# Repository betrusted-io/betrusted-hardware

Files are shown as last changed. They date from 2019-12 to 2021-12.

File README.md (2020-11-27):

# betrusted-hardware

This is the Betrusted hardware design files repository.

All the designs are preliminary and have bugs. You have been warned. 

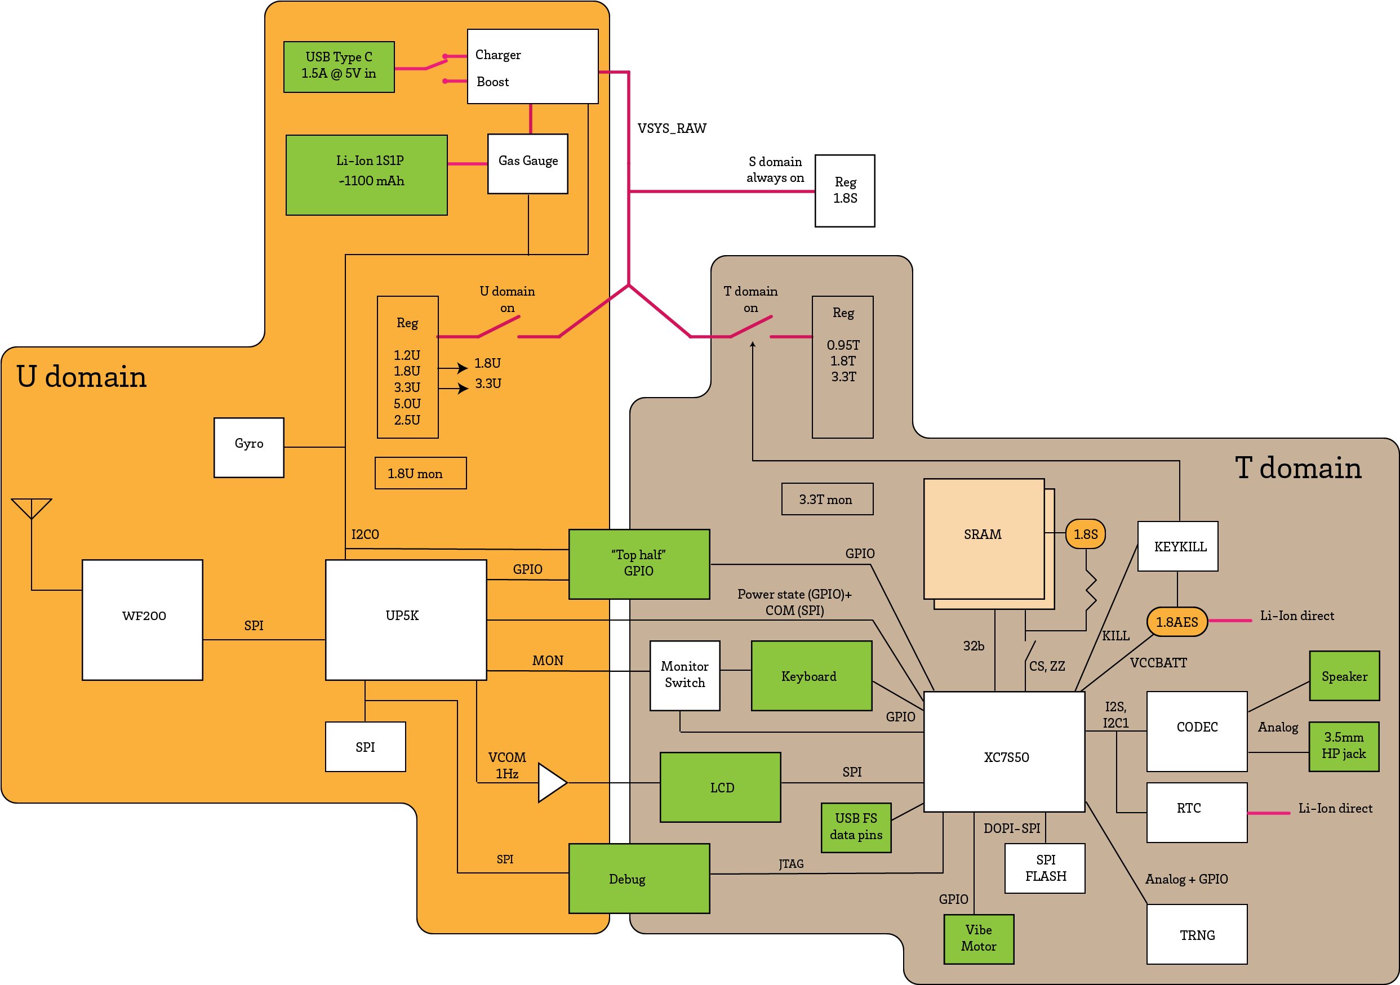
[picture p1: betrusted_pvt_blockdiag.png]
block diagram


Above is a block diagram of the mainboard, as of PVT1.

## Contribution Guidelines



Please see [CONTRIBUTING](CONTRIBUTING.md) for details on
how to make a contribution.

Please note that this project is released with a
[Contributor Code of Conduct](CODE_OF_CONDUCT.md).
By participating in this project you agree to abide its terms.

## License

Copyright © 2019

Licensed under the [CERN OHL v1.2](https://ohwr.org/project/licenses/wikis/cern-ohl-v1.2) [LICENSE](LICENSE)

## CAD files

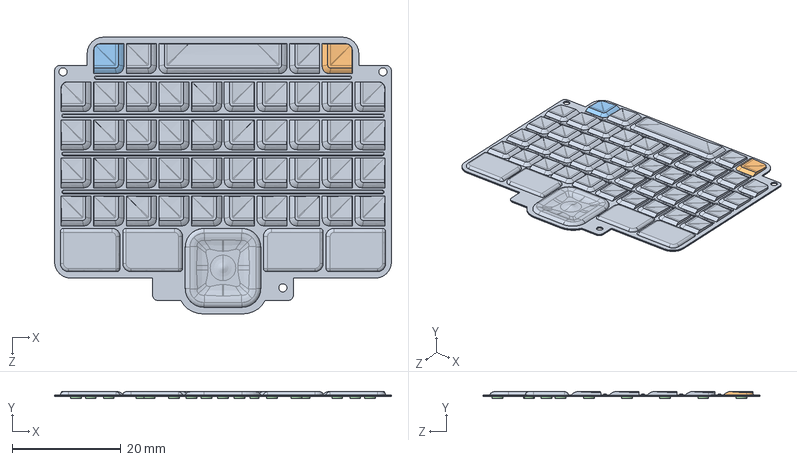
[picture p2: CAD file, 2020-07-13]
kbd-v3/overlays/kbd-v5-dvt.SLDASM
61.9 x 1.23 x 50.9 mm
kbd-v5-dvt
keycap
Mirrorkeycap
kbd-v5-bumps

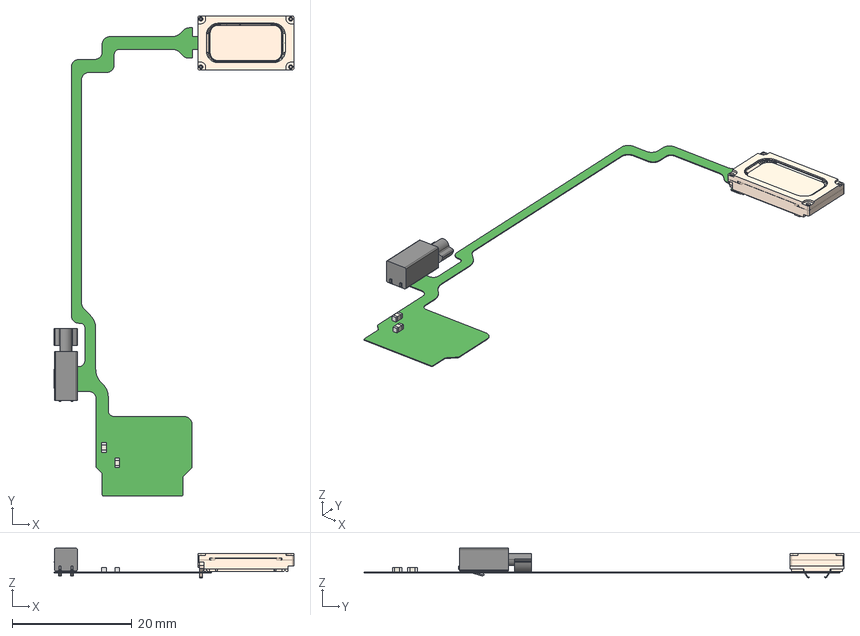
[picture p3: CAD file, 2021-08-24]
fpc-pvt2/bt-fpc-pvt2b.step
40.0 x 80.1 x 4.94 mm
vibe_motor_jinlong_Z32th7b2882001d_RGB4408131
CUI_CMS-16093-076S-67
Extruded x 6

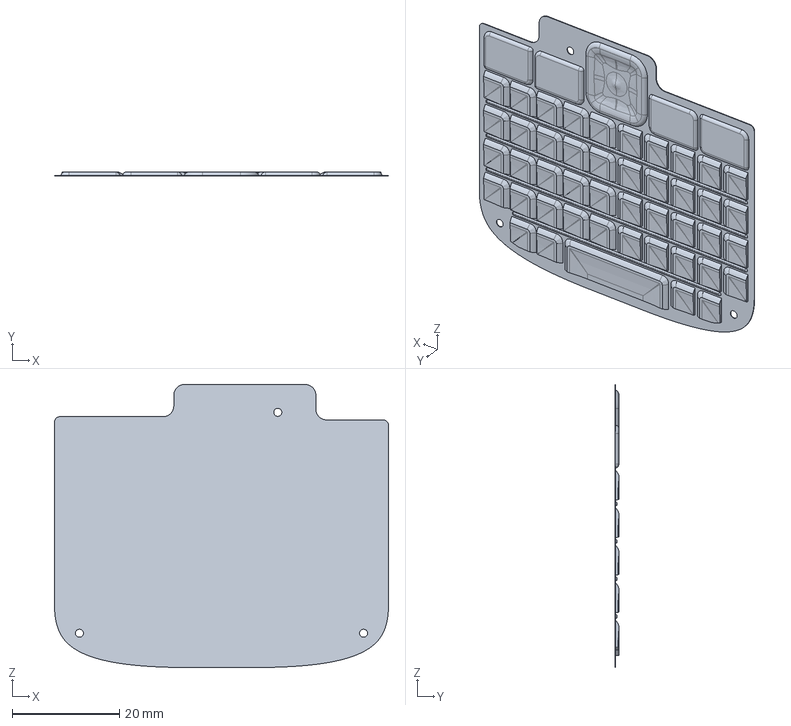
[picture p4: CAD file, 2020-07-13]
kbd-v3/overlays/kbd-v4-vendor.stp
62.3 x 0.725 x 52.8 mm

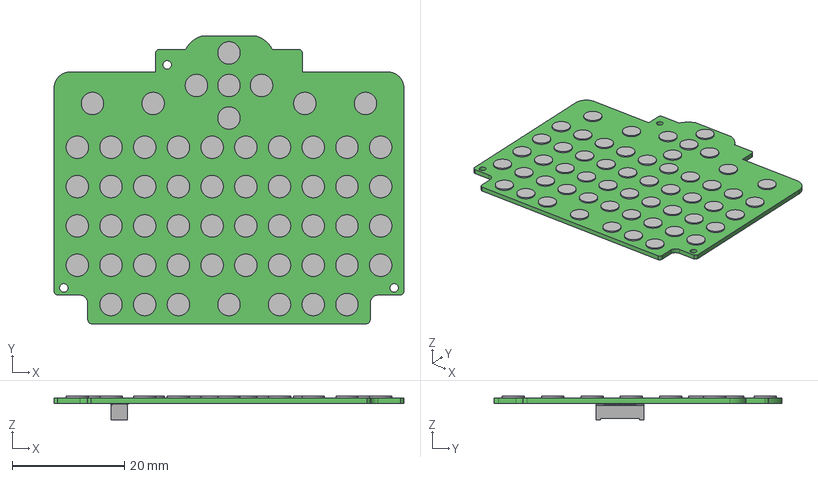
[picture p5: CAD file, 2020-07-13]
kbd-v3/pcb/bt-kbd-v3a.step
62.3 x 51.2 x 4.19 mm
DF40HC(3.0)-30DS

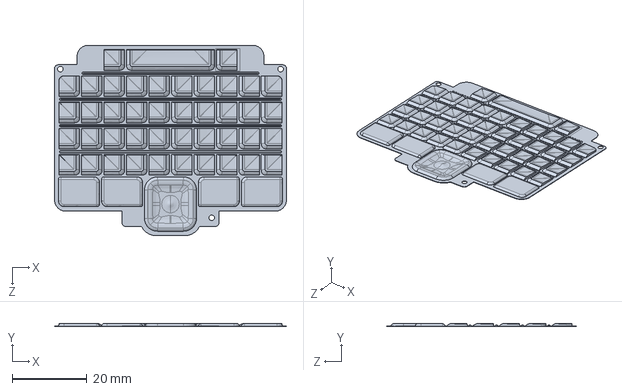
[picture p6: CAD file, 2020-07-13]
kbd-v3/overlays/kbd-v5-keycap.SLDPRT
61.9 x 0.725 x 50.9 mm

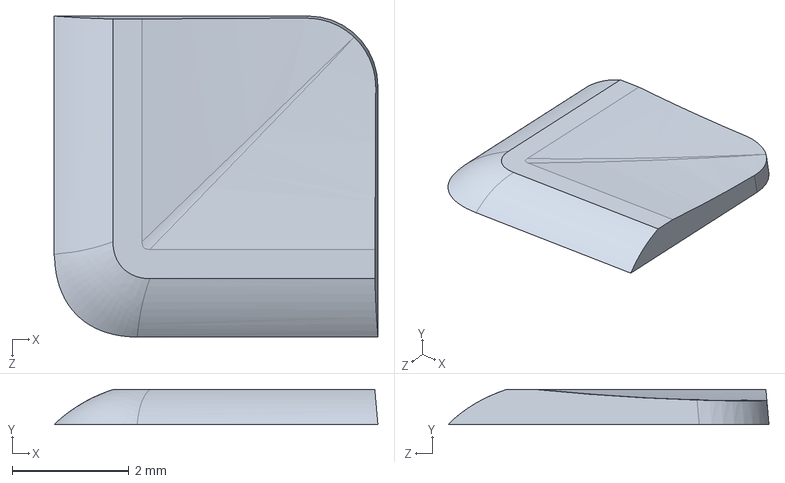
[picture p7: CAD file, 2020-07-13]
kbd-v3/overlays/keycap.sldprt
5.55 x 0.6 x 5.50 mm

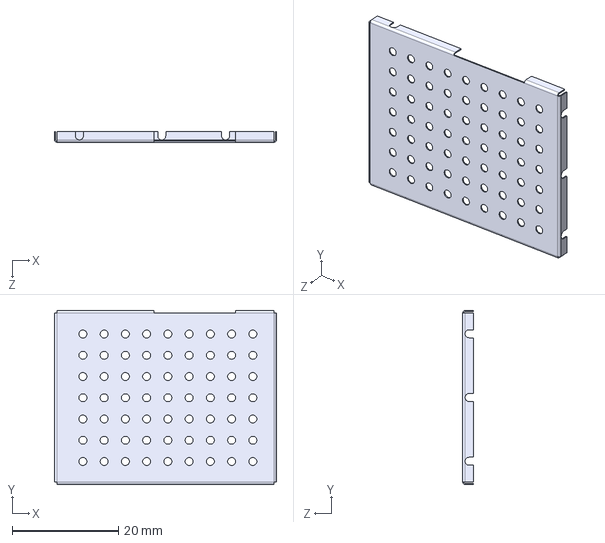
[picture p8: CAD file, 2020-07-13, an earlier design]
case-v1/t-domain-shield-032520.STEP
41.8 x 32.8 x 2.00 mm

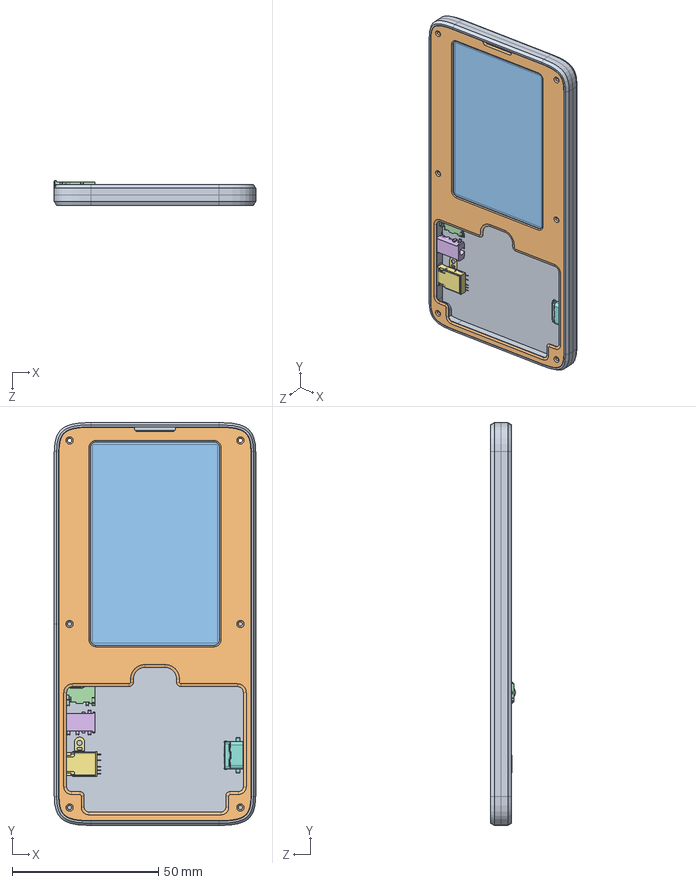
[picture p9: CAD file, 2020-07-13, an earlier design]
case-v1/betrusted-dvt1-top-sketch.SLDASM
69.0 x 138.0 x 8.50 mm
bottom-case
front-bezel
sharp_ls032b7dd02-folded-cable
CUI_SJ-43504-SMT-TR x 2
CX90B1-24P.stp
CUI_DEVICES_SJ-43615TS-SMT-TR
CUI_DEVICES_SJ-3542AS-SMT-TR-67
c-1-2295018-2-b-3d
pcb-max-extent

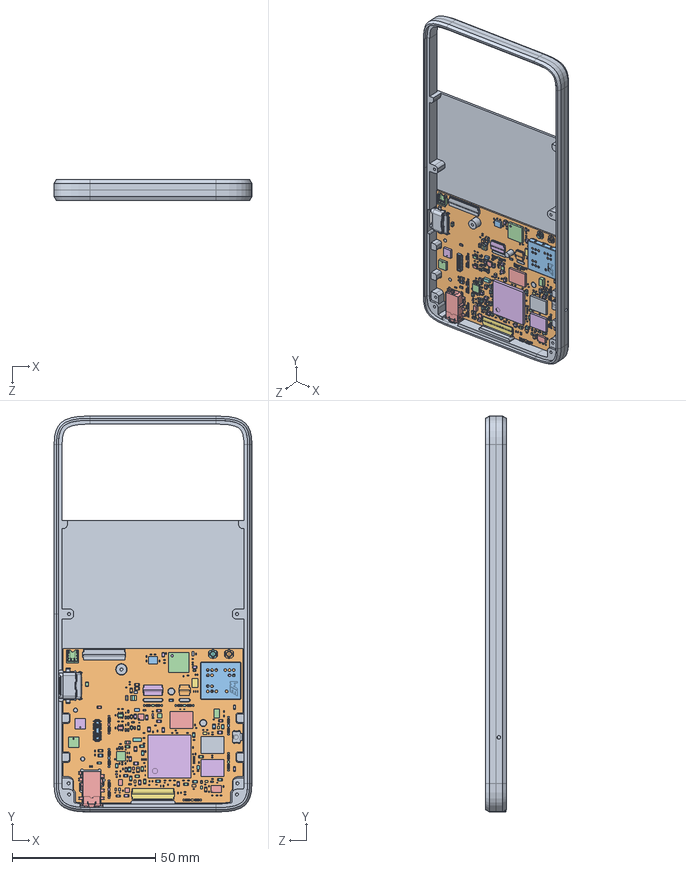
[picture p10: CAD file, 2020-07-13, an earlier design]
case-v1/dvt1-pcb-fitting.SLDASM
69.0 x 138.0 x 7.20 mm
bottom-case
36900000_Download_STP_WE-SHC-36900000_rev1^T-SHIELD8testfit_dvt1-test-mb(2)_dvt1-test-mb
36900000_Download_STP_WE-SHC-36900000_rev1^T-SHIELD7testfit_dvt1-test-mb(2)_dvt1-test-mb
36900000_Download_STP_WE-SHC-36900000_rev1^T-SHIELD6testfit_dvt1-test-mb(2)_dvt1-test-mb
36900000_Download_STP_WE-SHC-36900000_rev1^T-SHIELD5testfit_dvt1-test-mb(2)_dvt1-test-mb
Extruded^6956128896_U13Mtestfit_dvt1-test-mb(2)_dvt1-test-mb
Extruded-0^7163059696_R14Mtestfit_dvt1-test-mb(2)_dvt1-test-mb x 2
Extruded-1^7163062416_R14Mtestfit_dvt1-test-mb(2)_dvt1-test-mb
Extruded-2^7161943424_L10Mtestfit_dvt1-test-mb(2)_dvt1-test-mb x 2
Extruded-3^7161944304_L10Mtestfit_dvt1-test-mb(2)_dvt1-test-mb
Extruded-4^6098454064_J10Mtestfit_dvt1-test-mb(2)_dvt1-test-mb x 2
Extruded-5^6098454464_J10Mtestfit_dvt1-test-mb(2)_dvt1-test-mb
Extruded-6^6098170912_C20Mtestfit_dvt1-test-mb(2)_dvt1-test-mb
Extruded-7^6098171472_C20Mtestfit_dvt1-test-mb(2)_dvt1-test-mb x 2
Extruded-8^6480486112_C19Mtestfit_dvt1-test-mb(2)_dvt1-test-mb
Extruded-9^6480485872_C19Mtestfit_dvt1-test-mb(2)_dvt1-test-mb x 2
FH34SRJ-4S-0.5SH^P13Wtestfit_dvt1-test-mb(2)_dvt1-test-mb
Open_CASCADE_STEP_translator_6.8_3.1.1^Terminal_7706544704_D15Wtestfit_dvt1-test-mb(2)_dvt1-test-mb
Open_CASCADE_STEP_translator_6.8_3.1.2^Terminal_7706544704_D15Wtestfit_dvt1-test-mb(2)_dvt1-test-mb
Open_CASCADE_STEP_translator_6.8_3.2.1^Mid_Body_7706544704_D15Wtestfit_dvt1-test-mb(2)_dvt1-test-mb
Open_CASCADE_STEP_translator_6.8_3.1.1^Terminal_7706544704_D14Wtestfit_dvt1-test-mb(2)_dvt1-test-mb
Open_CASCADE_STEP_translator_6.8_3.1.2^Terminal_7706544704_D14Wtestfit_dvt1-test-mb(2)_dvt1-test-mb
Open_CASCADE_STEP_translator_6.8_3.2.1^Mid_Body_7706544704_D14Wtestfit_dvt1-test-mb(2)_dvt1-test-mb
Open_CASCADE_STEP_translator_6.8_3.1.1^Terminal_7706544704_D13Wtestfit_dvt1-test-mb(2)_dvt1-test-mb
Open_CASCADE_STEP_translator_6.8_3.1.2^Terminal_7706544704_D13Wtestfit_dvt1-test-mb(2)_dvt1-test-mb
Open_CASCADE_STEP_translator_6.8_3.2.1^Mid_Body_7706544704_D13Wtestfit_dvt1-test-mb(2)_dvt1-test-mb
Open_CASCADE_STEP_translator_6.8_3.1.1-15^Terminal-1_9704169984_D12Wtestfit_dvt1-test-mb(2)_dvt1-test-mb
Open_CASCADE_STEP_translator_6.8_3.1.2-16^Terminal-1_9704169984_D12Wtestfit_dvt1-test-mb(2)_dvt1-test-mb
Open_CASCADE_STEP_translator_6.8_3.2.1-17^Mid_Body-1_9704169984_D12Wtestfit_dvt1-test-mb(2)_dvt1-test-mb
Open_CASCADE_STEP_translator_6.8_3.1.1-15^Terminal-1_9704169984_D11Wtestfit_dvt1-test-mb(2)_dvt1-test-mb
Open_CASCADE_STEP_translator_6.8_3.1.2-16^Terminal-1_9704169984_D11Wtestfit_dvt1-test-mb(2)_dvt1-test-mb
Open_CASCADE_STEP_translator_6.8_3.2.1-17^Mid_Body-1_9704169984_D11Wtestfit_dvt1-test-mb(2)_dvt1-test-mb
36900000_Download_STP_WE-SHC-36900000_rev1^T-SHIELD4testfit_dvt1-test-mb(2)_dvt1-test-mb
36900000_Download_STP_WE-SHC-36900000_rev1^T-SHIELD3testfit_dvt1-test-mb(2)_dvt1-test-mb
36900000_Download_STP_WE-SHC-36900000_rev1^T-SHIELD2testfit_dvt1-test-mb(2)_dvt1-test-mb
CUI_SJ-43504-SMT-TR^P10Utestfit_dvt1-test-mb(2)_dvt1-test-mb
Open_CASCADE_STEP_translator_6.8_13.2.1^Body_6846069104_U11Ftestfit_dvt1-test-mb(2)_dvt1-test-mb
Open_CASCADE_STEP_translator_6.8_13.1^6846069104_U11Ftestfit_dvt1-test-mb(2)_dvt1-test-mb
ball^6846069104_U11Ftestfit_dvt1-test-mb(2)_dvt1-test-mb x 324
c-1-2295018-2-b-3d^P10Ptestfit_dvt1-test-mb(2)_dvt1-test-mb
3610213126S_Download_STP_WE-SHC-3610213126S_rev1^W-SHIELDtestfit_dvt1-test-mb(2)_dvt1-test-mb
3600213120S_Download_STP_WE-SHC-3600213120S_rev1^W-SHIELDtestfit_dvt1-test-mb(2)_dvt1-test-mb
Open_CASCADE_STEP_translator_6.8_15.2.1-21^Body-3_6806409824_U16Ktestfit_dvt1-test-mb(2)_dvt1-test-mb
Open_CASCADE_STEP_translator_6.8_15.4.1^Pin_Shape-1_6806409824_U16Ktestfit_dvt1-test-mb(2)_dvt1-test-mb x 14
Open_CASCADE_STEP_translator_6.8_15.1-22^6806409824_U16Ktestfit_dvt1-test-mb(2)_dvt1-test-mb
Thermal_Shape^6806409824_U16Ktestfit_dvt1-test-mb(2)_dvt1-test-mb
36900000_Download_STP_WE-SHC-36900000_rev1^T-SHIELD1testfit_dvt1-test-mb(2)_dvt1-test-mb
Extruded-0^7163059696_R35Ptestfit_dvt1-test-mb(2)_dvt1-test-mb x 2
Extruded-1^7163062416_R35Ptestfit_dvt1-test-mb(2)_dvt1-test-mb
Extruded-12^7163062816_R34Ftestfit_dvt1-test-mb(2)_dvt1-test-mb x 2
Extruded-1^7163062416_R34Ftestfit_dvt1-test-mb(2)_dvt1-test-mb
Extruded-1^7163062416_C13Ftestfit_dvt1-test-mb(2)_dvt1-test-mb
Extruded-12^7163062816_C13Ftestfit_dvt1-test-mb(2)_dvt1-test-mb x 2
Extruded-12^7163062816_C12Ftestfit_dvt1-test-mb(2)_dvt1-test-mb x 2
Extruded-1^7163062416_C12Ftestfit_dvt1-test-mb(2)_dvt1-test-mb
Extruded-25^6938092112_U15Ktestfit_dvt1-test-mb(2)_dvt1-test-mb
Extruded-12^7163062816_C27Ktestfit_dvt1-test-mb(2)_dvt1-test-mb x 2
Extruded-1^7163062416_C27Ktestfit_dvt1-test-mb(2)_dvt1-test-mb
Extruded-1^7163062416_C74Ftestfit_dvt1-test-mb(2)_dvt1-test-mb
Extruded-0^7163059696_C74Ftestfit_dvt1-test-mb(2)_dvt1-test-mb x 2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

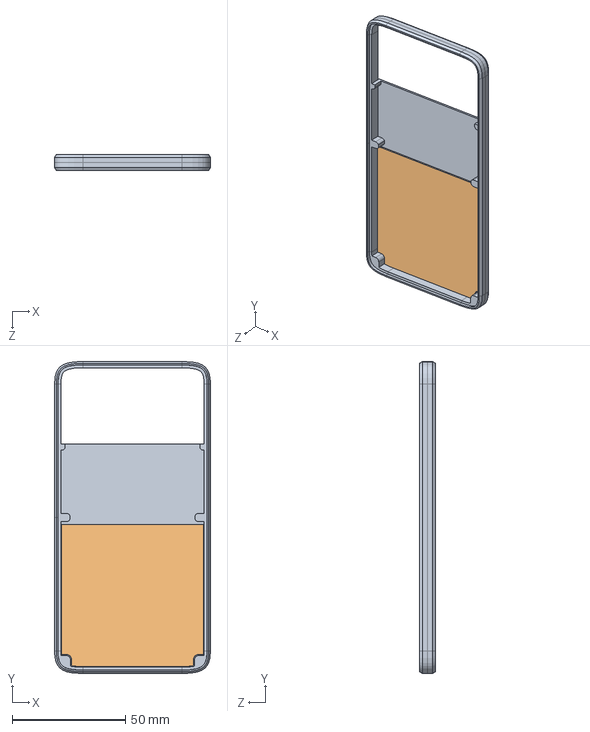
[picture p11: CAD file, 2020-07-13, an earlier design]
case-v1/betrusted-dvt1-pcbfit.SLDASM
69.0 x 138.0 x 7.20 mm
bottom-case
pcb-max-extent

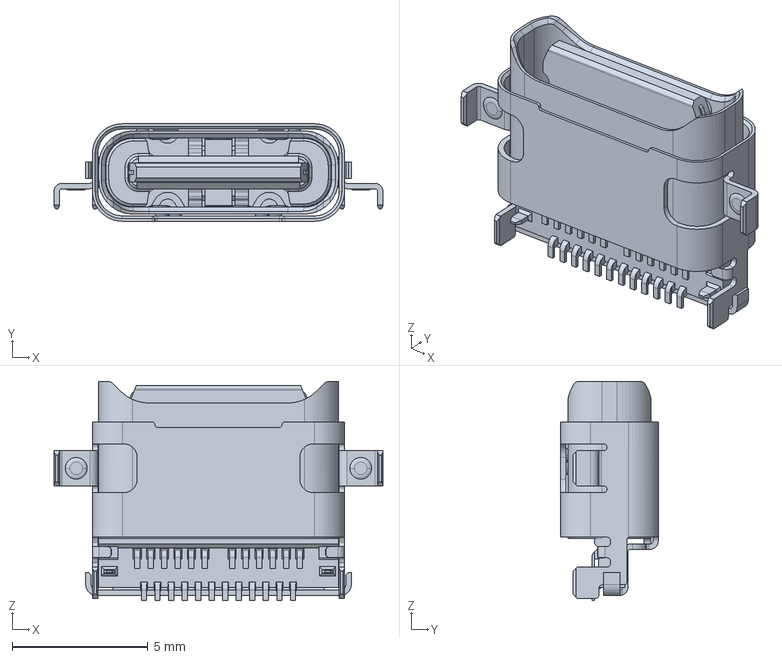
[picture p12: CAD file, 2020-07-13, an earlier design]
case-v1/c-1-2295018-2-b-3d.stp
12.1 x 3.60 x 8.10 mm

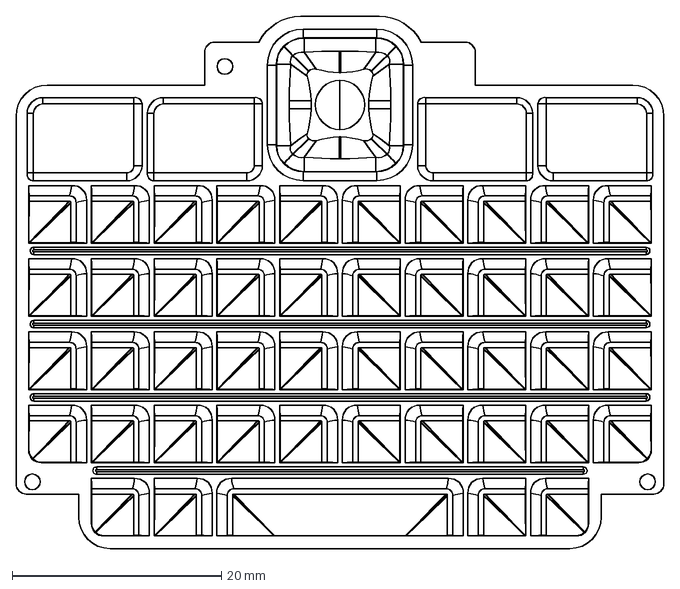
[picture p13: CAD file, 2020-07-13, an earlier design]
case-v1/fab/kbd-v5-dvt.DXF
61.9 x 50.9 mm

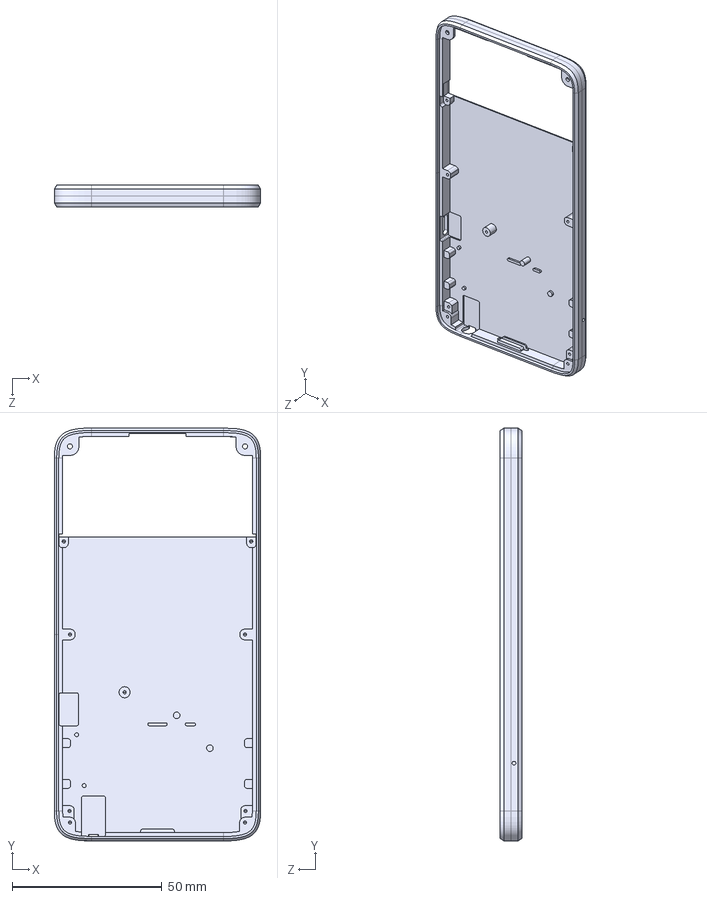
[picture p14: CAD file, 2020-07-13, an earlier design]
case-v1/fab/bottom-case.STEP
69.0 x 138.0 x 7.20 mm

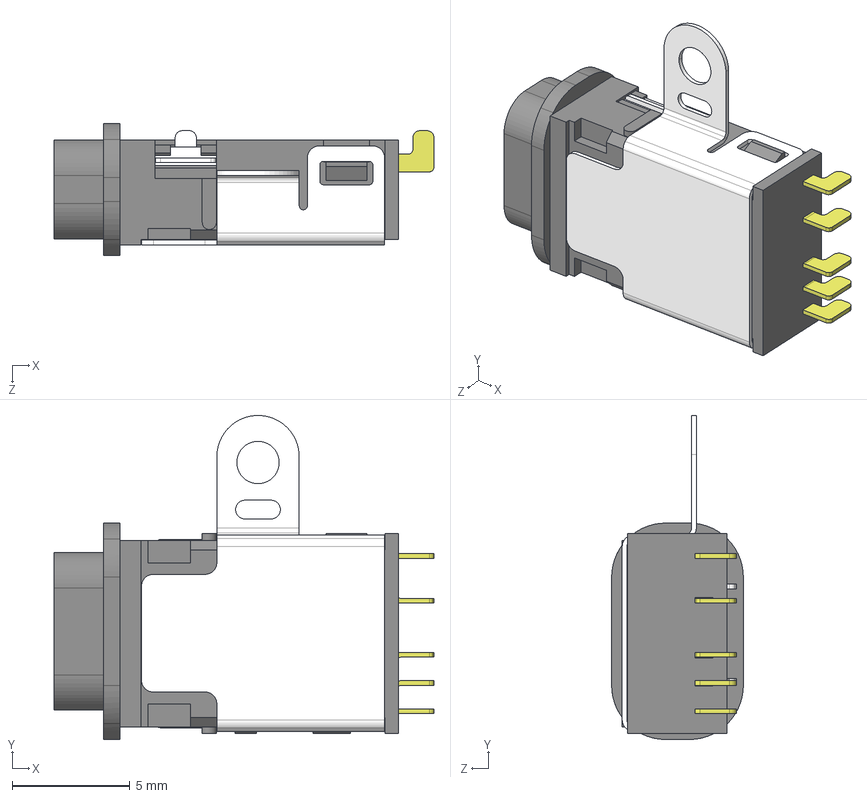
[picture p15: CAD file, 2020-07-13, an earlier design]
case-v1/CUI_DEVICES_SJ-3542AS-SMT-TR-67.step
16.2 x 13.8 x 5.60 mm

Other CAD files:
kbd-v3/overlays/Mirrorkeycap.sldprt
kbd-v3/overlays/kbd-v5-bumps.SLDPRT
case-v1/t-domain-shield.STEP
case-v1/master-profile.SLDPRT
case-v1/CUI_DEVICES_SJ-3542AS-SMT-TR-67.SLDPRT
case-v1/CUI_DEVICES_SJ-43615TS-SMT-TR.SLDPRT
case-v1/CUI_DEVICES_SJ-43615TS-SMT-TR.step
case-v1/CUI_SJ-43504-SMT-TR.SLDPRT
case-v1/CUI_SJ-43504-SMT-TR.step
case-v1/CX90B1-24P_4800497000_3D.SLDASM
case-v1/CX90B1-24P_4800497000_3D.stp
case-v1/LH-32005A-200407-backlight.SLDPRT
case-v1/LH-35038A_200321.dwg
case-v1/betrusted-dvt1-fpc-dims.DXF
case-v1/betrusted-dvt1-fpc-dims.SLDDRW
case-v1/betrusted-dvt1-pcbfit.DXF
case-v1/betrusted-dvt1-pcbfit.SLDDRW
case-v1/bl-spec-example.SLDDRW
case-v1/bottom-case-032420.STEP
case-v1/bottom-case.SLDPRT
case-v1/bt-kbd-v3a.SLDASM
case-v1/bt-kbd-v3a.step
case-v1/c-1-2295018-2-b-3d.SLDPRT
case-v1/cable-path.SLDDRW
case-v1/dvt1-test-mb.SLDDRW
case-v1/fab/bottom-case.SLDDRW
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

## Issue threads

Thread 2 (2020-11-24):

Altium schematics reference non-embedded image

cibomahto, 2020-11-24:
Thanks for providing these as open hardware designs!

The '00_map.SchDoc' files in both the truste_io_evt2 and trusted_io_dvt1 projects are missing embedded images:
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

bunnie, 2020-11-24:
Good call! thanks for pointing that out. I clicked the "embed" button on the UI and hopefully that saved the image into the .SchDoc file with commit https://github.com/betrusted-io/betrusted-hardware/commit/6c061859211b1b64149b644710691fd966f53876.

If this fixes it for you, please close the issue!

Closed 2020-11-24.

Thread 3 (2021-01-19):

Question: Disabling Wifi

xloem, 2021-01-19:
It is such a breath of fresh air to see how security conscious your work is.

I couldn't see what the plans were for providing non-networked use of a device.  Is there a way to physically cut power to, and/or remove, the wifi chip?

bunnie, 2021-01-19:
The wifi chip is firewalled via an FPGA that is in the "untrusted" domain, but the FPGA is still open source and you control its function. To that end, there are many simple ways to permanently defeat the wifi chip. The easiest is to just hold its RESET line asserted. Another option would be to remove or damage the clock chip that provides its timebase; or you could remove or damage the ferrite beads that supply power to the analog/RF section, if for some reason you have suspicion that the chip could somehow still run RESET asserted and the clock stopped.

xloem, 2021-01-20:
Thank you for the detailed reply.

If you ever redesign, add my vote in for hardware switches/blowable fuses to cut power to radios, sensors, actuators, or general modularity =)

Closed 2021-01-20.

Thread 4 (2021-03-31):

Include IPC Netlist in Release Files

xobs, 2021-03-31:
An IPC netlist can be used to recreate some of the schematic information from the resulting Gerber and NC Drill files.

It would be nice to include this file in the release output.

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

xobs, 2021-03-31:
That's exactly it. That can be used to validate connectivity, or to produce neat files like this:

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

(Note: I'm using DVT1b gerbers, which is why things are sometimes out of place or askew)

bunnie, 2021-03-31:
'k. I've added this to the default generation set but I have to remember to check it into github. I'll leave this issue open in an attemp to remind myself to do that when time comes for the next release.

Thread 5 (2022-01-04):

The "trick" to make the keyboard more power efficient

dumblob, 2022-01-04:
IIRC I saw somewhere a "trick" to even further preserve power by keeping some parts of the keyboard low instead of under current.

I can't find it though now - could you point me to the relevant places (design parts if any and then the corresponding firmware code)?

Thanks!

bunnie, 2022-01-04:
Maybe you're referring to this section?

https://github.com/betrusted-io/betrusted-ec/blob/4310e7c4ceef986580d42d3da15c089eaf5f9ded/sw/src/main.rs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

The basic issue with the keyboard was getting it so that the pull-ups to sense the hit on a keyboard didn't bleed current into the sometimes powered-off FPGA, which was primarily accomplished by the introduction of isolation FETs (U12K on the mainboard schematic). Before the FETs were introduced some diddling about was done with tri-state drive etc. to limit the amount of time stuff was driven high due to the high leakage into the powered-off FPGA.

dumblob, 2022-01-05:
That's exactly it! Thanks!

Closed 2022-01-05.

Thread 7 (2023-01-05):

Create Github-compatible versions of layouts

xobs, 2023-01-05:
The layouts are in Adobe Illustrator format, which isn't usable with Github. It may be possible to set up a CI task to automatically generate .svg files from the .ai files using e.g. http://www.xs4all.nl/~hanwen/public/software/ai2svg.py

bunnie, 2023-01-05:
Which files does this refer to? The board layouts are done with Altium, not Illustrator...

xobs, 2023-01-05:
The keyboard layouts look like they're done in Illustrator: https://github.com/betrusted-io/betrusted-hardware/tree/main/kbd-v3/layouts

xobs, 2023-01-05:
For background: This came about because I wanted to show what they keyboard layouts look like, and I had to download the file and screenshot it, rather than directly linking to an image.

bunnie, 2023-01-05:
Ah yes. When I read the issue it say "the layouts" and I thought it was referring to the circuit board layouts, which is most of what this repo is dedicated to.

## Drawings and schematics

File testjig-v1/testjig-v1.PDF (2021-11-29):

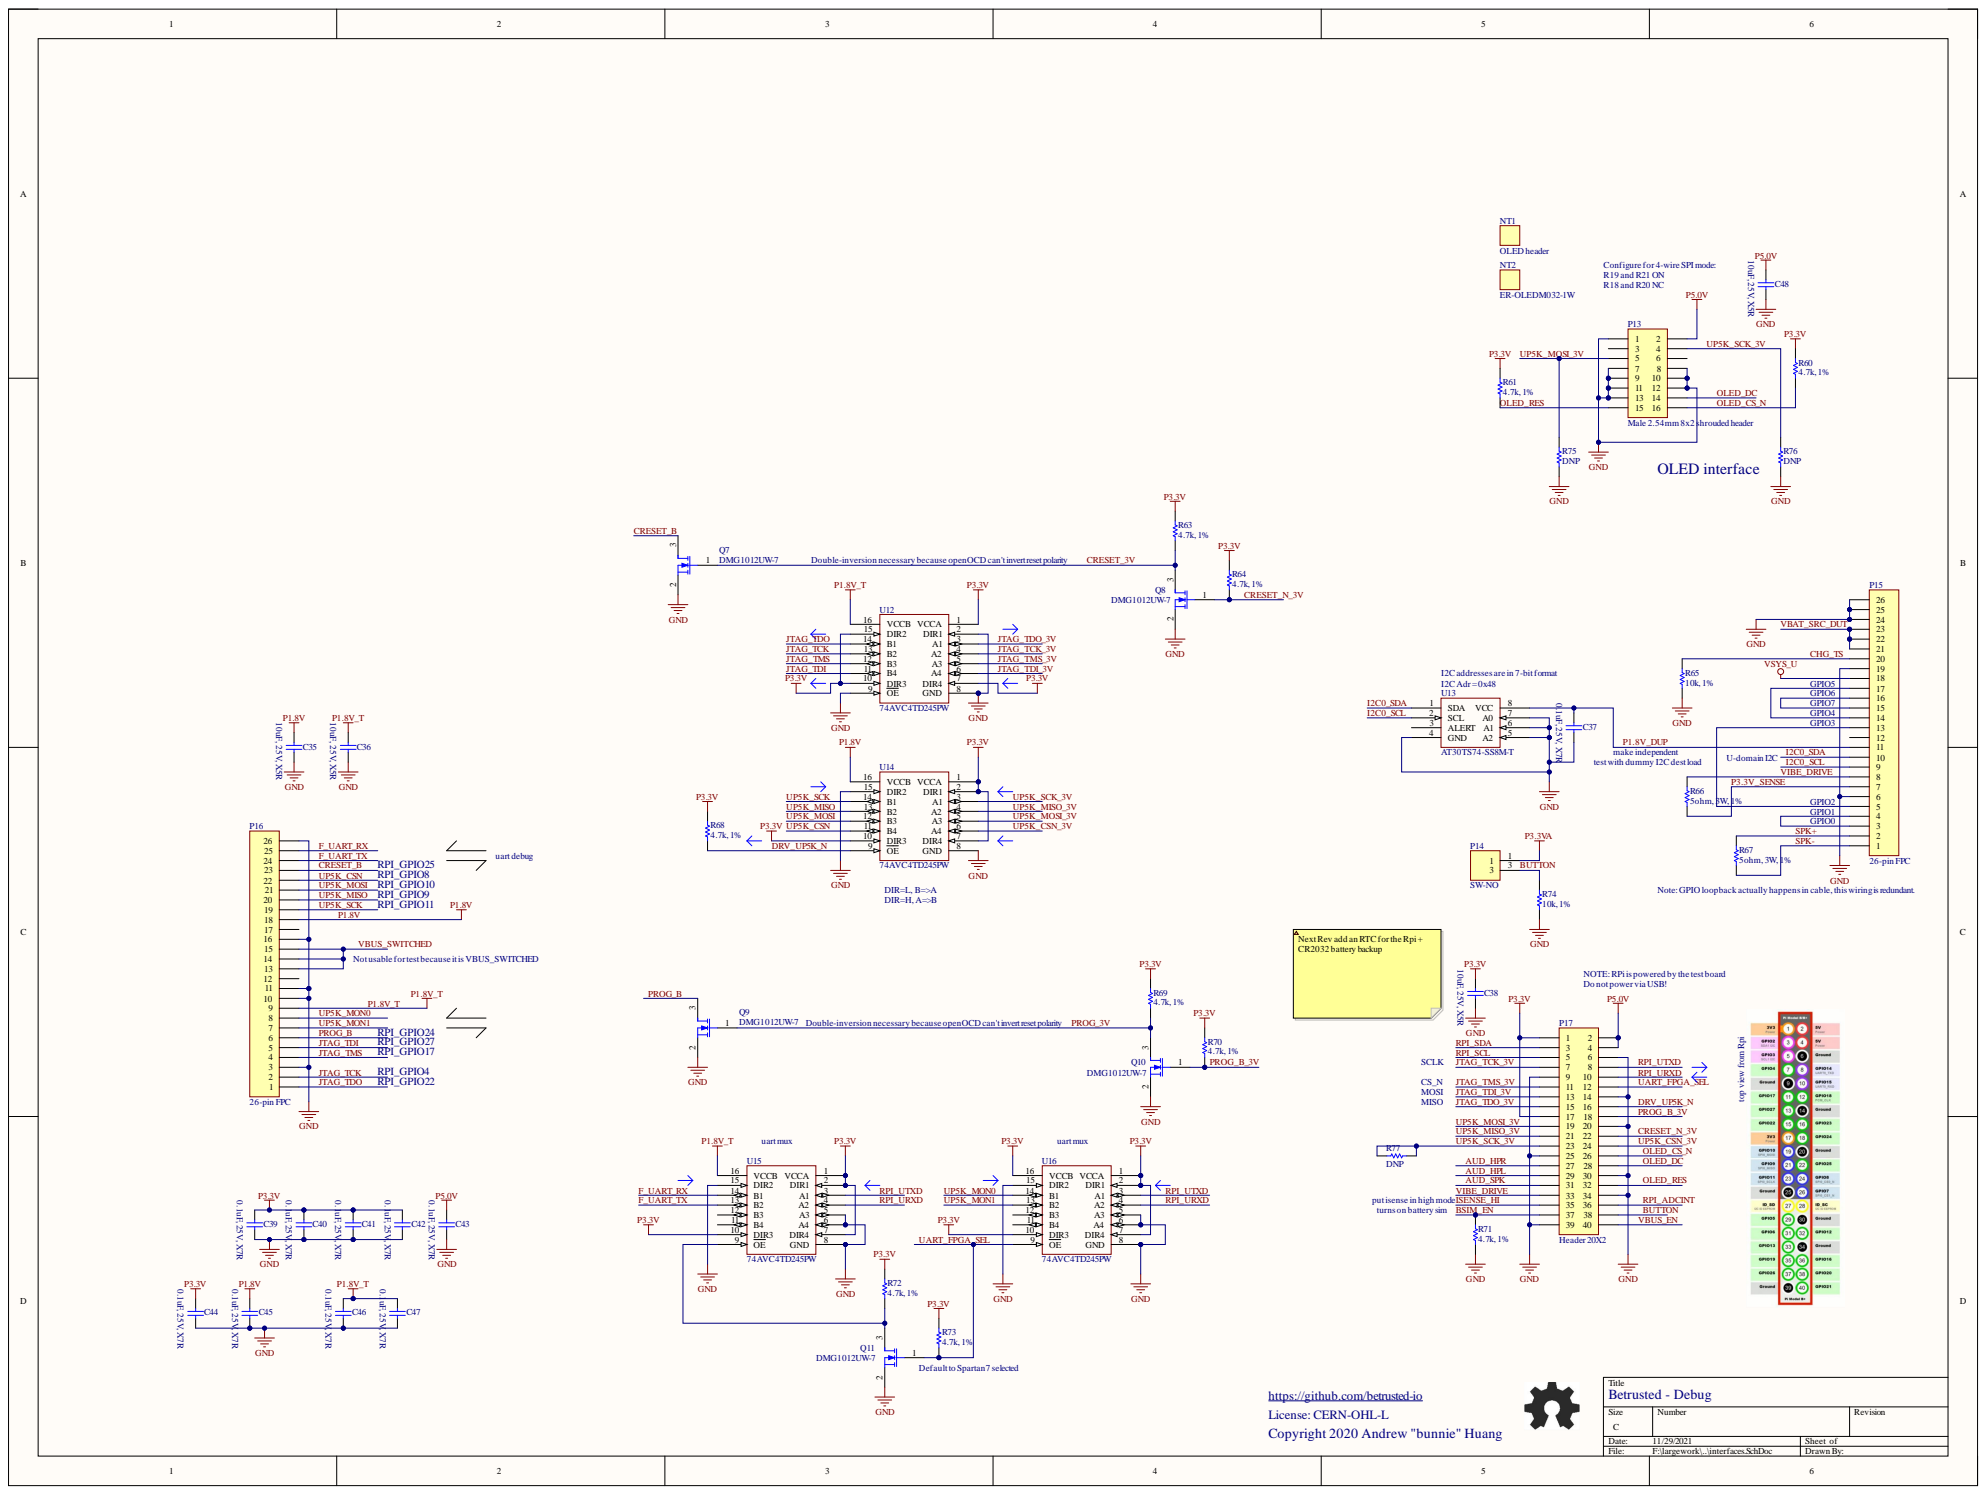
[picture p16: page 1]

Configure for 4-wire SPI mode:
R19 andR21 ON
R18 andR20 NC

OLED_DC

Double-inversion necessary because openOCDcan'tinvertresetpolarity

Note:GPIOloopback actually happensin cable, thiswiringisredundant.

NextRev add anRTC for theRpi+
CR2032 battery backup

NOTE:RPiis powered by the testboard
Do notpower via USB!

top view from Rpi

putisense in high mode
turns on battery sim

https://github.com/betrusted-io
License: CERN-OHL-L
Copyright 2020 Andrew "bunnie" Huang

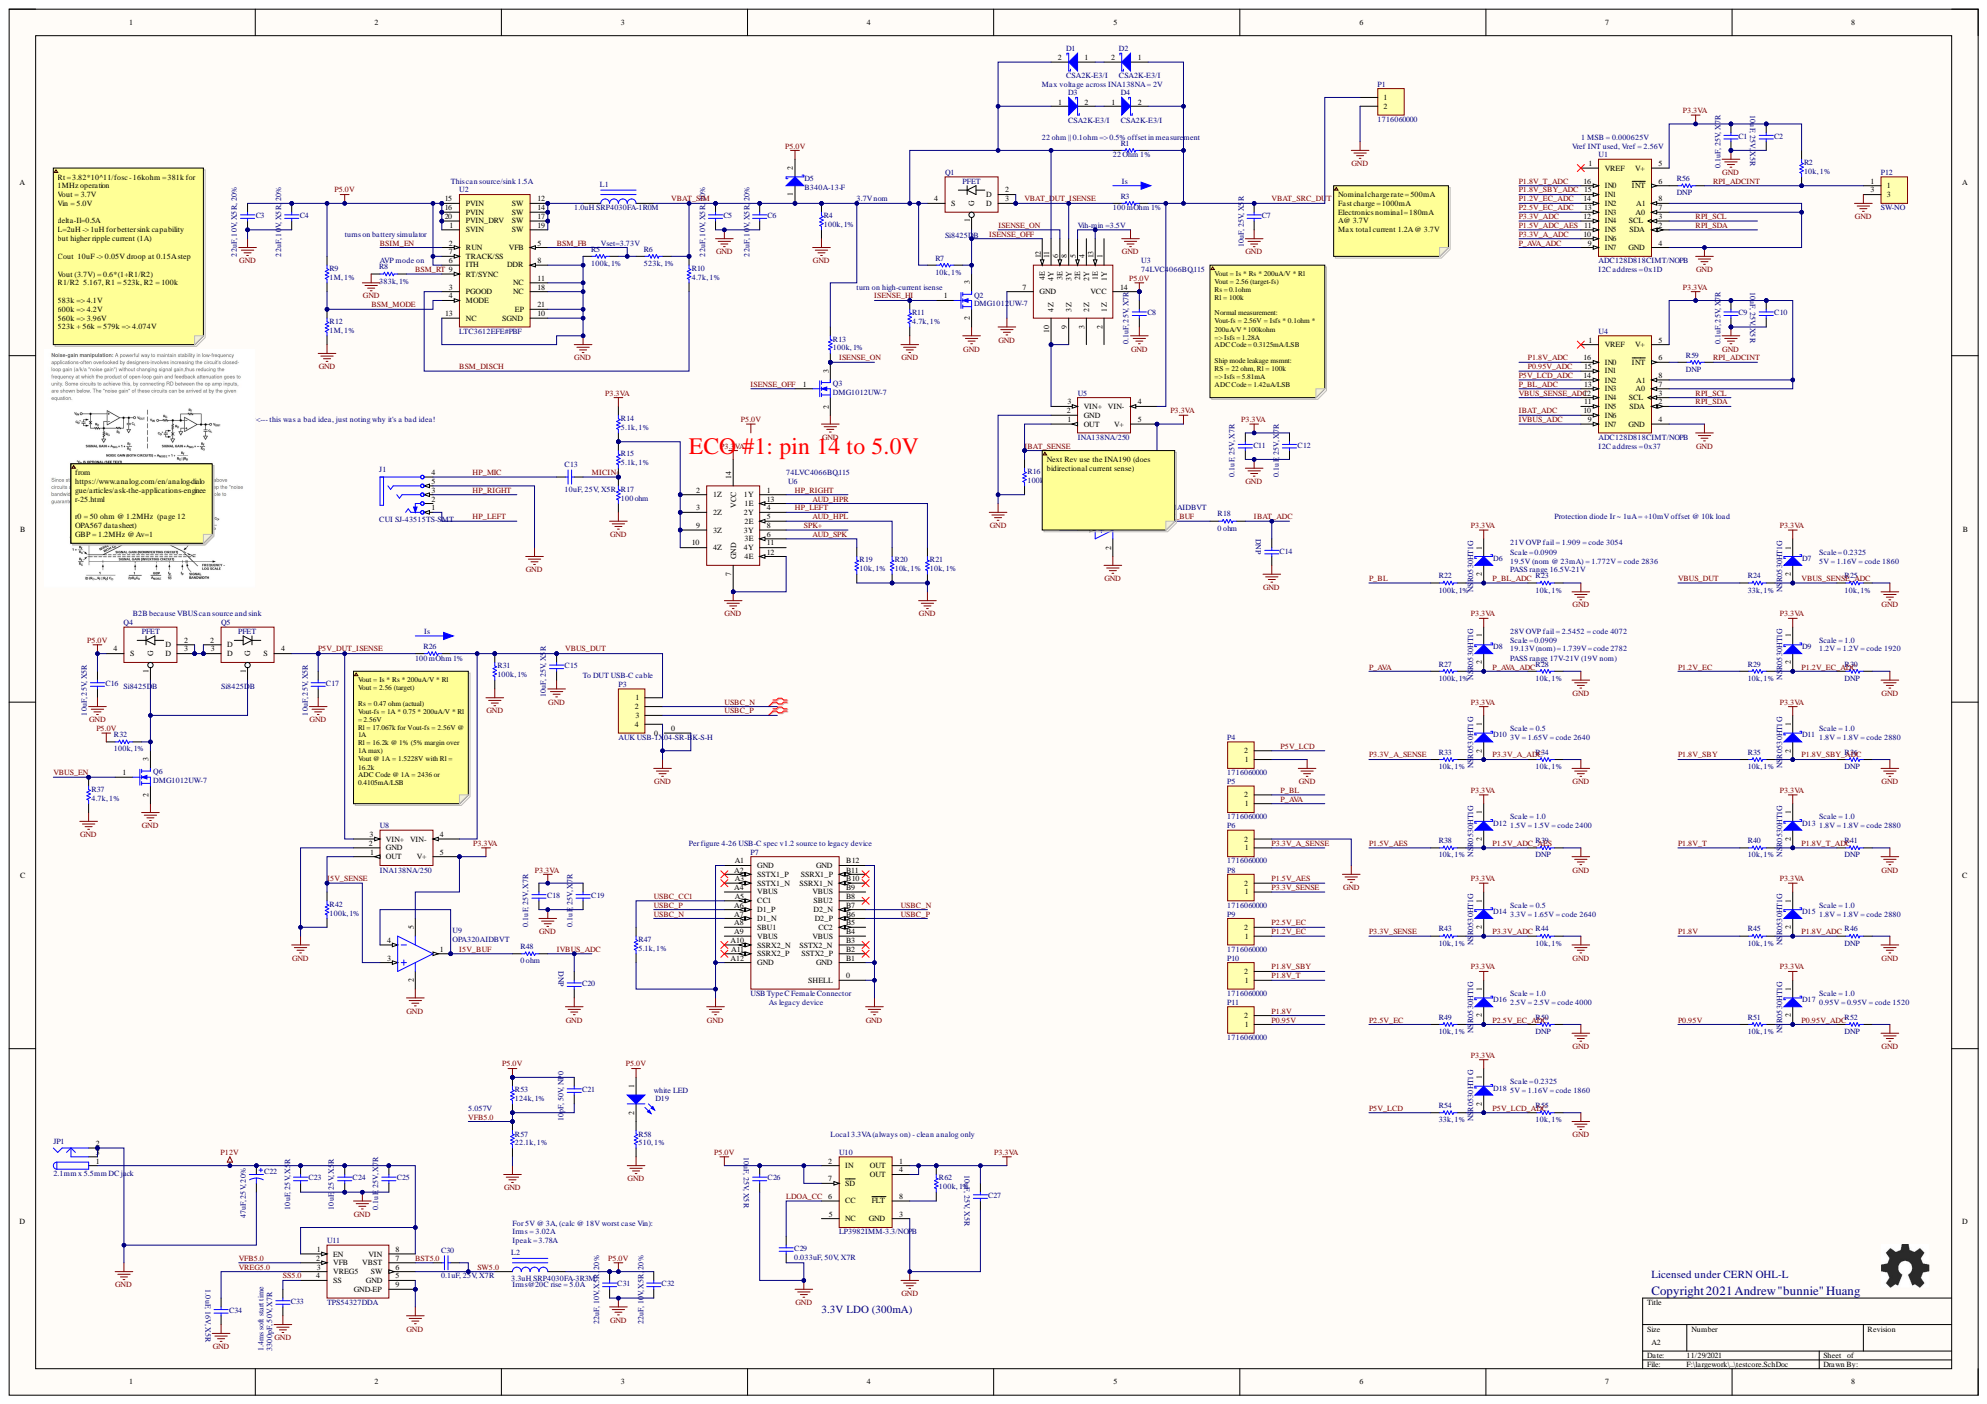
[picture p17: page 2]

22 ohm || 0.1ohm =>0.5% offset in measurement

1 MSB = 0.000625V
Vref INT used, Vref = 2.56V

delta-Il=0.5A
L=2uH ->1uH for bettersink capability
but higher ripple current (1A)

turns on battery simulator

ITH 6 TRACK/SS 7 | R5

Vout = Is * Rs * 200uA/V * Rl
Vout = 2.56 (target-fs)
Rs = 0.1ohm

turn on high-current isense
ISENSE_HI

Ship mode leakage msmnt:
RS = 22 ohm, Rl = 100k
=> Isfs = 5.81mA
ADC Code = 1.42uA/LSB

<--- this was a bad idea, just noting why it's a bad idea!

from
https://www.analog.com/en/analog-dialo
gue/articles/ask-the-applications-enginee
r-25.html

Protection diode Ir ~ 1uA= +10mV offset @ 10k load

B2B because VBUScan source and sink
PFET

To DUT USB-C cable

Vout = 2.56 (target)

AUK USB-1X04-SR-BK-S-H

Per figure 4-26 USB-C spec v1.2 source to legacy device

USB Type C Female Connector
As legacy device

Local 3.3VA(always on) - clean analog only

Licensed under CERN OHL-L
Copyright 2021 Andrew "bunnie" Huang
Title

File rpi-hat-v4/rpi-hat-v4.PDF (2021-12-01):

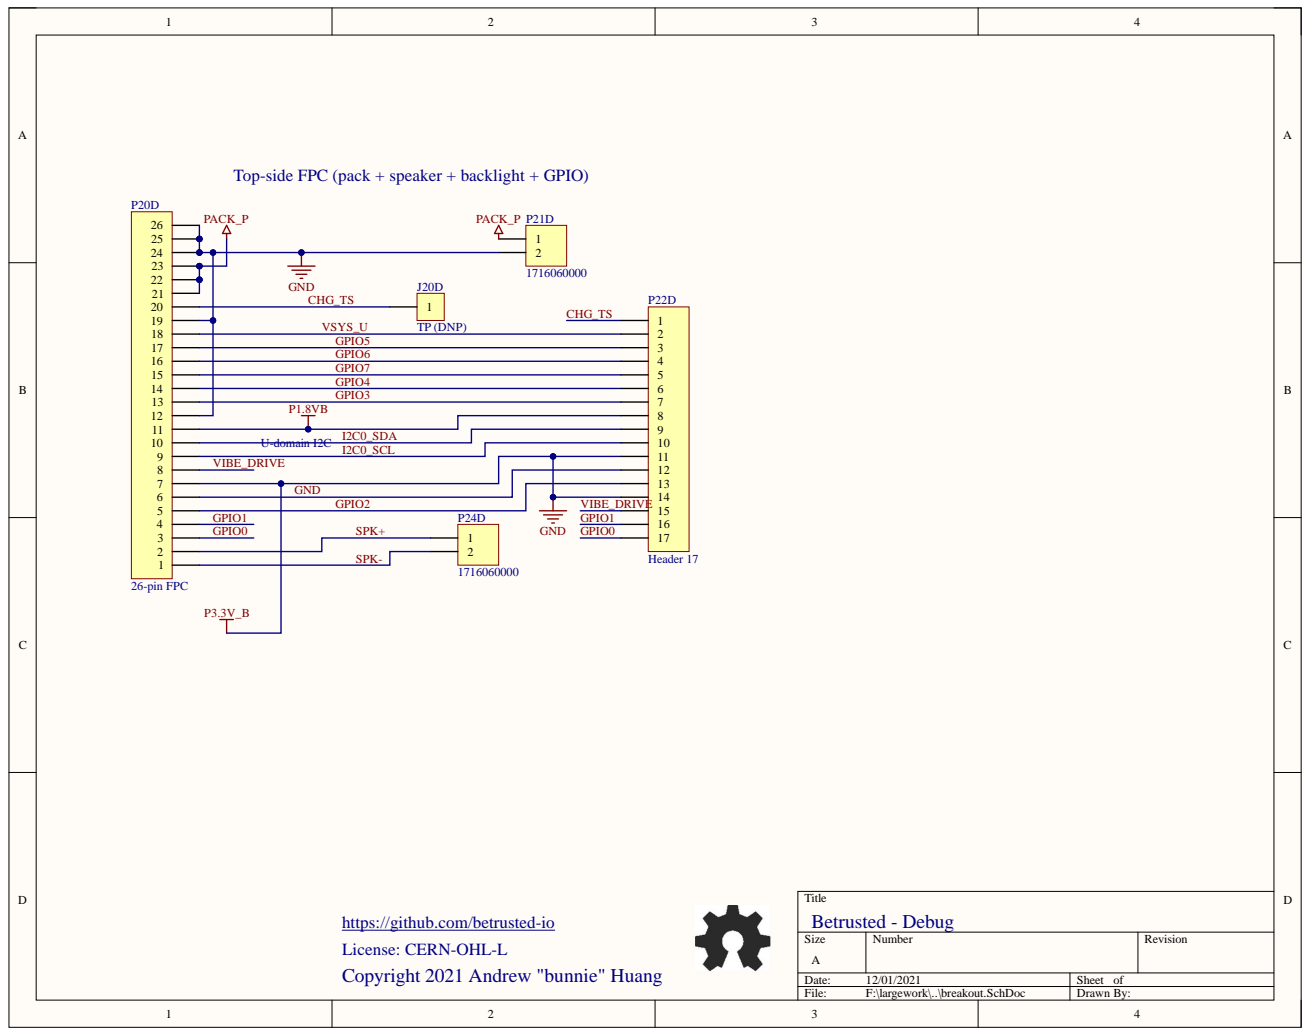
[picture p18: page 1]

Top-side FPC (pack + speaker + backlight + GPIO)

GPIO5
GPIO6
GPIO7
GPIO4
GPIO3

I2C0_SDA U-domain I2C

I2C0_SCL

VIBE_DRIVE

GND

GPIO2 | VIBE_DRIVE

GPIO1 | P24D

License: CERN-OHL-L
Copyright 2021 Andrew "bunnie" Huang

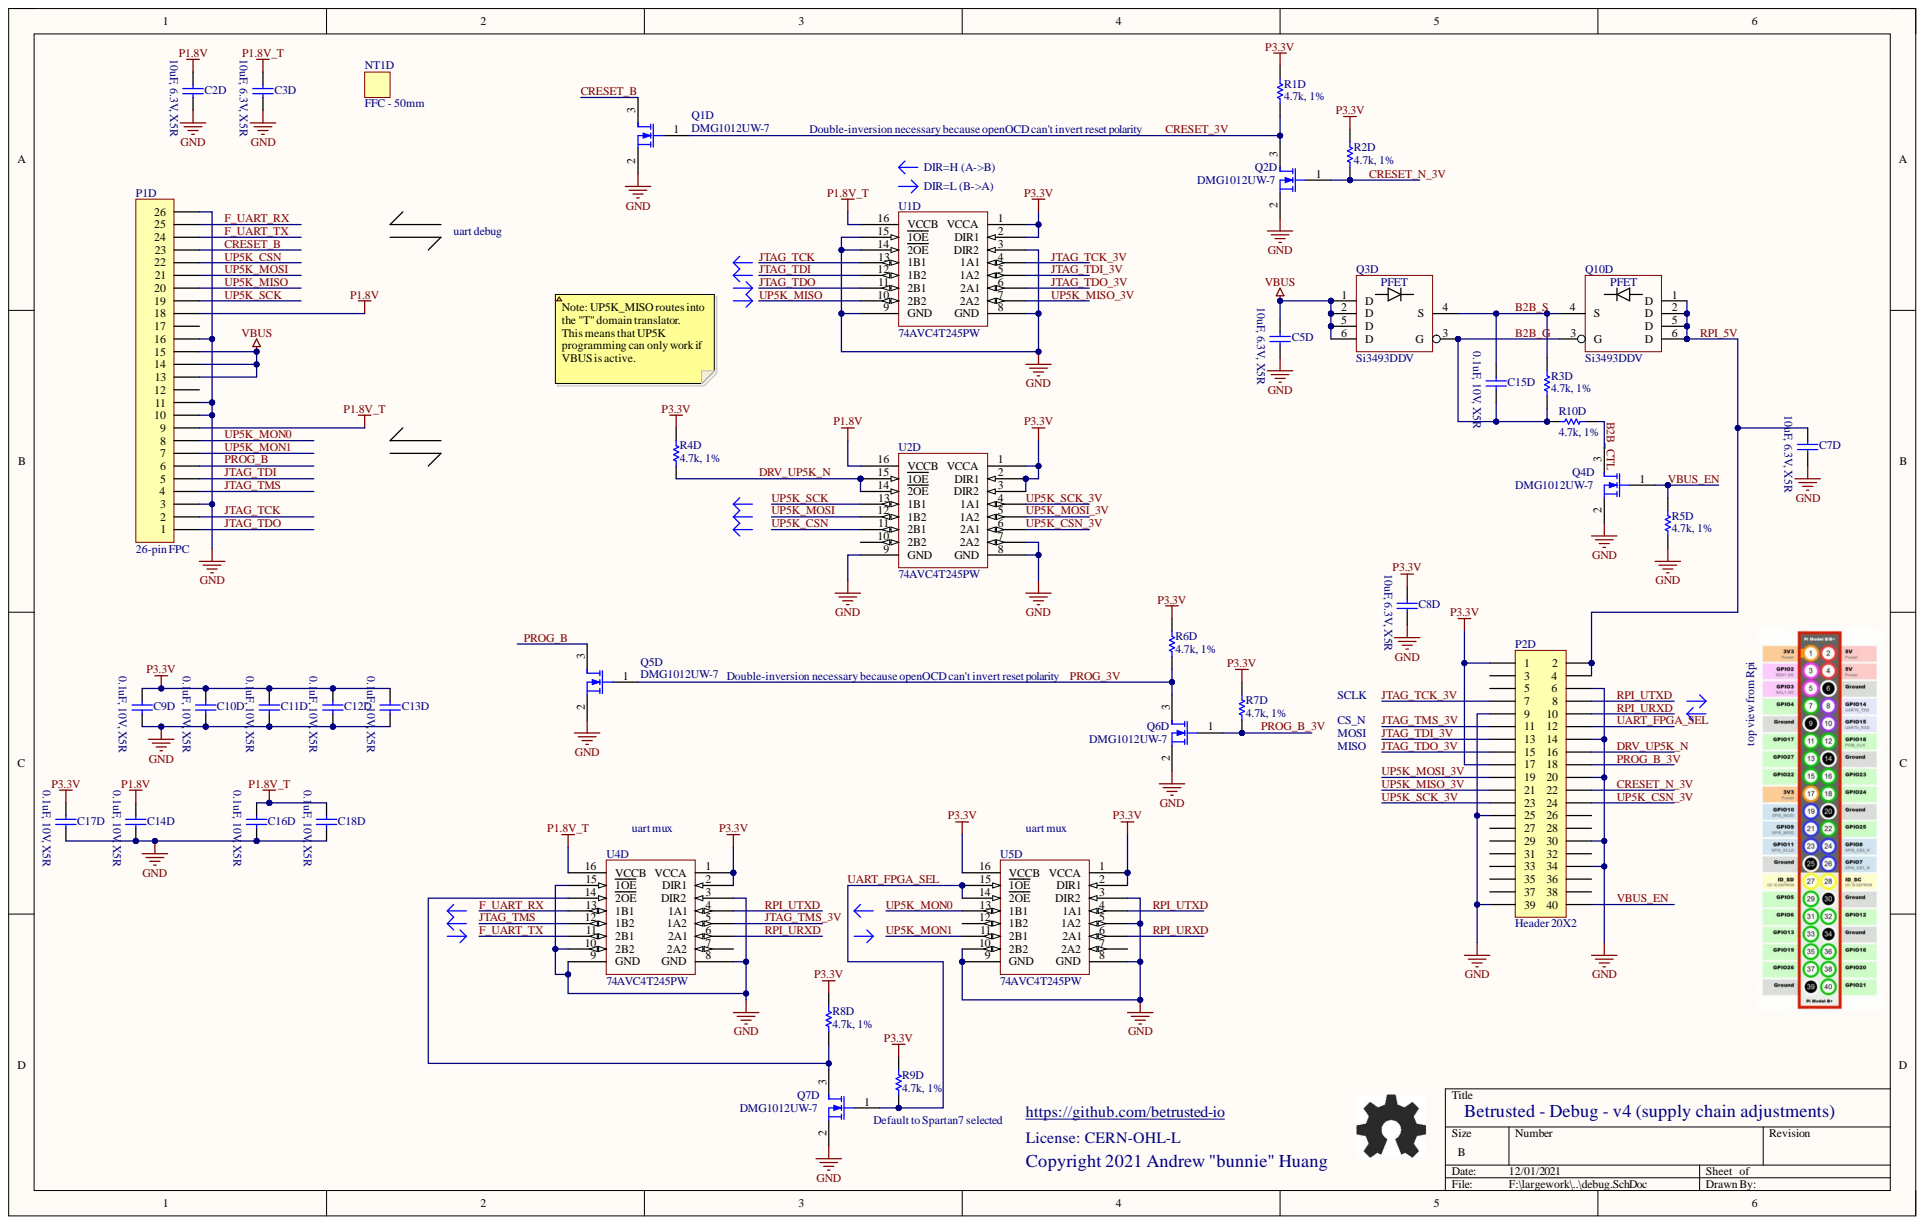
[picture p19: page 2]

Double-inversion necessary because openOCDcan't invert reset polarity

Note: UP5K_MISOroutesinto
the "T" domain translator.
This meansthat UP5K
programming can only work if
VBUS is active.

https://github.com/betrusted-io
License: CERN-OHL-L
Copyright 2021 Andrew "bunnie" Huang

Title
Betrusted - Debug - v4 (supply chain adjustments)

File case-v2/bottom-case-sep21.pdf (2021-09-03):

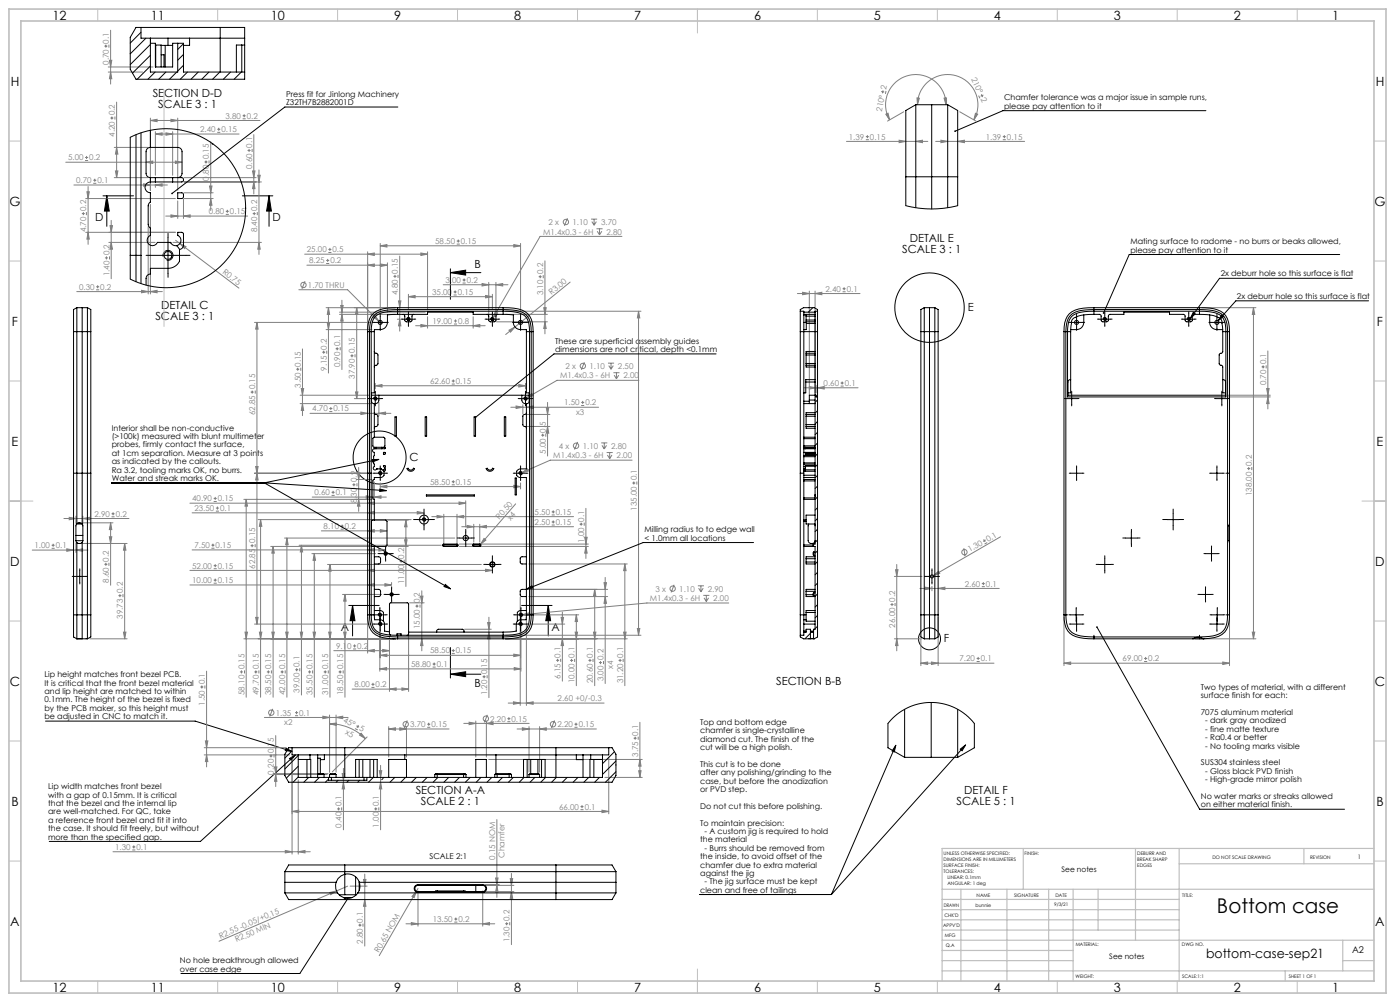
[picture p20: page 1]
3.00 0.2 1.70 THRU 0.90 0.1; R2.55 -0.05/+0.15 R2.50 MIN; R0.65 NOM; 0.15 NOM; SCALE 2:1; SECTION A-A SCALE 2 : 1; SECTION B-B; DETAIL C SCALE 3 : 1; Press fit for Jinlong Machinery; SCALE 3 : 1; DETAIL E SCALE 3 : 1; DETAIL F SCALE 5 : 1; FINISH:; DEBURR AND; BREAK SHARP; DO NOT SCALE DRAWING; REVISION; SCALE:1:1; SHEET 1 OF 1; See notes

SECTION D-D

Chamfer tolerance was a major issue in sample runs,
please pay attention to it

Mating surface to radome - no burrs or beaks allowed,

2x deburr hole so this surface is flat

These are superficial assembly guides
dimensions are not critical, depth <0.1mm

Interior shall be non-conductive
(>100k) measured with blunt multimeter
probes, firmly contact the surface,
at 1cm separation. Measure at 3 points
as indicated by the callouts.
Ra 3.2, tooling marks OK, no burrs.
Water and streak marks OK.

Milling radius to to edge wall
< 1.0mm all locations

Lip height matches front bezel PCB.

It is critical that the front bezel material
and lip height are matched to within
0.1mm. The height of the bezel is fixed
by the PCB maker, so this height must
be adjusted in CNC to match it.

Two types of material, with a different
surface finish for each:
7075 aluminum material
- dark gray anodized
- fine matte texture
- Ra0.4 or better
- No tooling marks visible
SUS304 stainless steel
- Gloss black PVD finish
- High-grade mirror polish
No water marks or streaks allowed
on either material finish.

Top and bottom edge
chamfer is single-crystalline
diamond cut. The finish of the
cut will be a high polish.
This cut is to be done
after any polishing/grinding to the
case, but before the anodization
or PVD step.
Do not cut this before polishing.
To maintain precision:
- A custom jig is required to hold
the material
- Burrs should be removed from
the inside, to avoid offset of the
chamfer due to extra material
against the jig
- The jig surface must be kept
clean and free of tailings

Lip width matches front bezel
with a gap of 0.15mm. It is critical

that the bezel and the internal lip
are well-matched. For QC, take
a reference front bezel and fit it into
the case. It should fit freely, but without
more than the specified gap.

UNLESS OTHERWISE SPECIFIED:
DIMENSIONS ARE IN MILLIMETERS
SURFACE FINISH:
TOLERANCES:
LINEAR: 0.1mm
ANGULAR: 1 deg

NAME | SIGNATURE | DATE | | | | TITLE: Bottom case

DRAWN | bunnie | | 9/3/21
CHK'D
APPV'D
MFG
Q.A | | | | MATERIAL: See notes | DWG NO. bottom-case-sep21 | A2

No hole breakthrough allowed
over case edge

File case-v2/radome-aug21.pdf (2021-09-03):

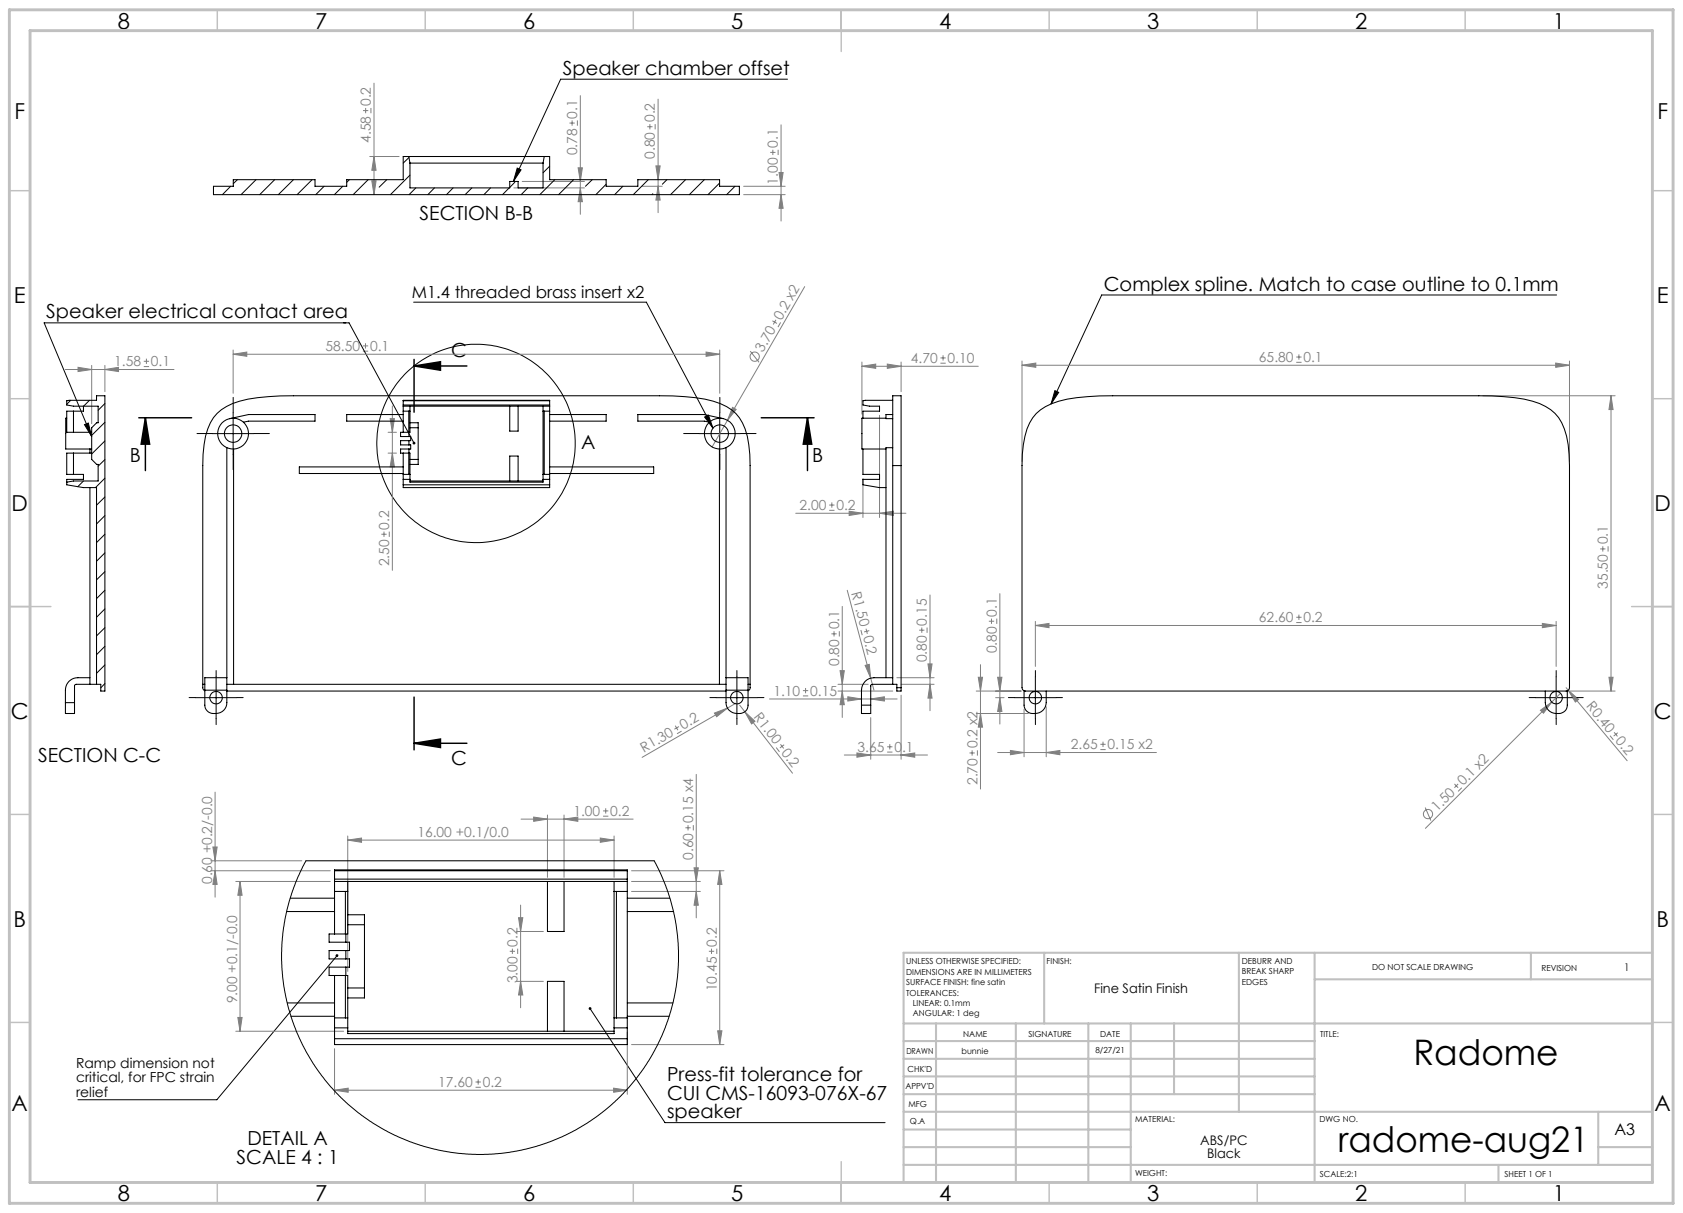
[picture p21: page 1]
DETAIL A SCALE 4 : 1; SECTION B-B; SECTION C-C; FINISH:; DEBURR AND; BREAK SHARP; DO NOT SCALE DRAWING; REVISION; SCALE:2:1; SHEET 1 OF 1

Speaker chamber offset | | | Complex spline. Match to case outline to 0.1mm

Speaker electrical contact area

M1.4 threaded brass insert x2

UNLESS OTHERWISE SPECIFIED:
DIMENSIONS ARE IN MILLIMETERS
SURFACE FINISH: fine satin
TOLERANCES:
LINEAR: 0.1mm
ANGULAR: 1 deg

Fine Satin Finish

NAME | SIGNATURE | DATE | | | | TITLE: Radome

DRAWN | bunnie | | 8/27/21
CHK'D
APPV'D
MFG
Q.A | | | | MATERIAL: Black | DWG NO. radome-aug21 | A3 ABS/PC

Ramp dimension not
critical, for FPC strain
relief

Press-fit tolerance for
CUI CMS-16093-076X-67
speaker

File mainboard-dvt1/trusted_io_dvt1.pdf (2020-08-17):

D | D
C | C
B | B
A | A

# Title

Size | Number | Revision

A

Date: | 4/04/2020 | Sheet of
File: | F:\largework\..\00_map.SchDoc | Drawn By:

# License: CERN-OHL-L

# Copyright © 2019 Andrew "bunnie" Huang

# Betrusted - Mainboard

# https://www.ohwr.org/project/cernohl/wikis/home

# https://github.com/betrusted-io

## Power sequencing:

* START with all systems off.
* VBUS (external power) applied, U, T, and S domains power on, and cannot be powered off until VBUS is removed. However, devices can still go into a power-saving mode on their own.

## * VBUS removed: * S-domain is always on

* T-domain only powers down when both CPU and UP5K approve it. Normally, UP5K should cut its override once the CPU is confirmed to boot, so effectively the CPU has sef-control for power down.
* U-domain can self-power down whenever, but normally it's meant to be always-on. It powers off only when the battery reaches 0% to protect the battery. U-domain manages all charge and gas gauge hardware, and reports status to T-domain via COM SPI interface.
* It is up to the T-domain to monitor power via firmware COM SPI interface to UP5K to coordinate on the 0% power down. UP5K can trigger an interrupt in case of emergency, but T domain retains full authority to ignore it.
* Once U-domain is powered down, CPU can power on with T_TO_U_ON. This is useful in case RTC wakes up FPGA and it needs to also wake up the UP5K.

The nominal power strategy is power-on boot, and after a certain time-out interval of no activity, the FPGA will power itself down completely, and rely on the U-domain to monitor wake-up keys to power the FPGA domain up, or a callback can be set for a wake-up at no later than a specified timeout.

* U-domain can activate keyboard backlights to give instant UX response to monitor key press.
* T-domain can deny U-domain monitoring of keys via hardware signal, to avoid information leakage between the two domains.
* T-domain controls the LCD backlight, if present.
* After a T-domain power-down, the U-domain has the option to discharge the voltage rails with FPGA_DIS. This is provisioned to guarantee power sequencing is met even if the FPGA power down is very brief.

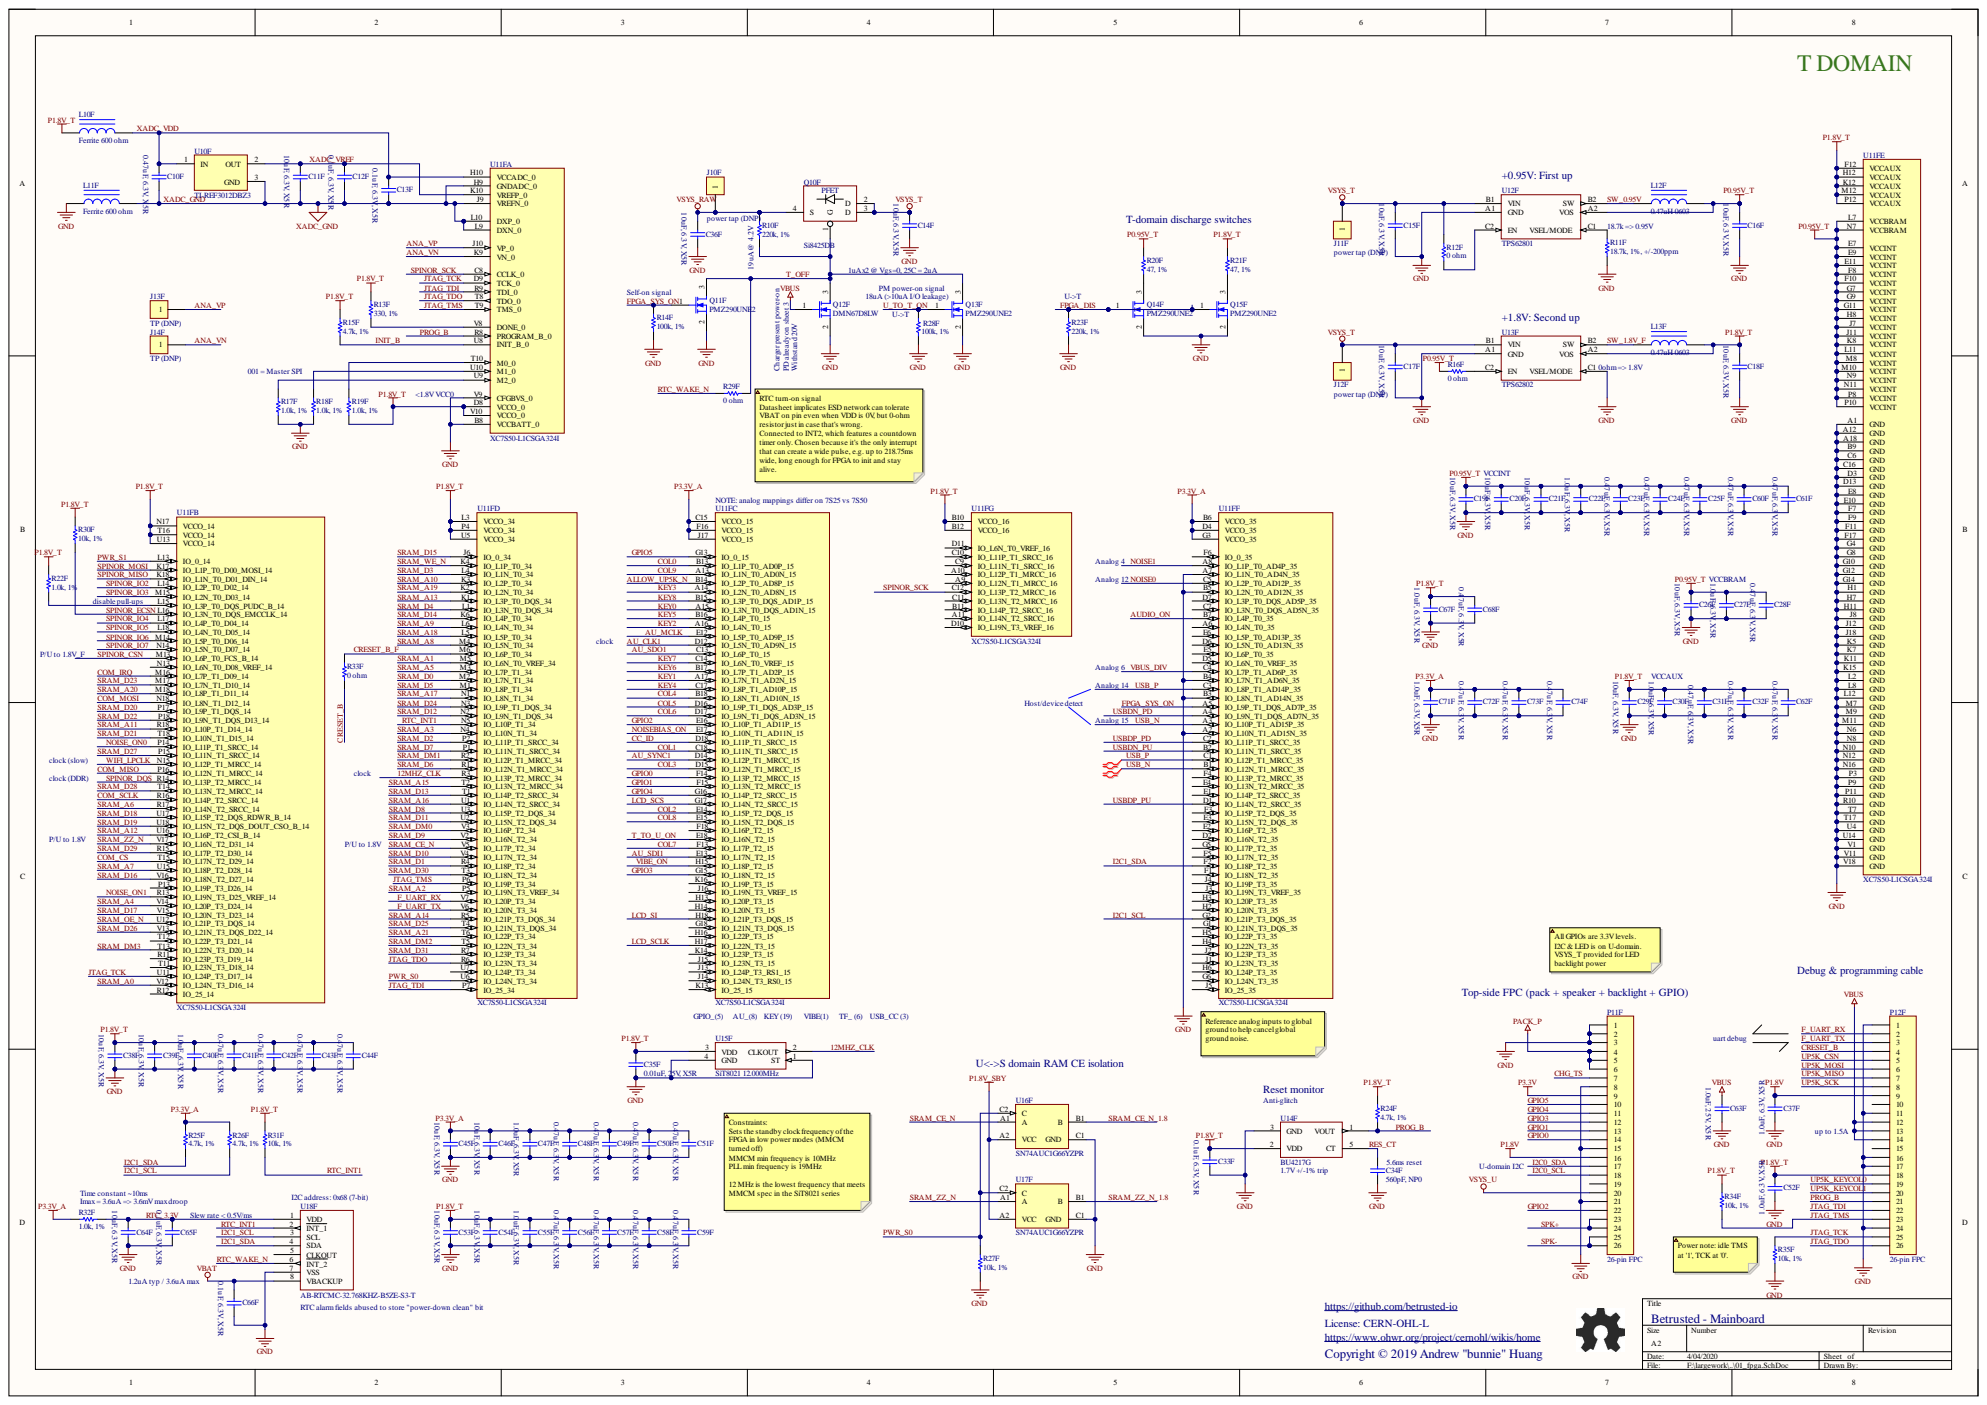
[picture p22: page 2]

Charger present power-on

PD already on sheet 3

RTC turn-on signal
Datasheet implicates ESD network can tolerate
VBAT on pin even when VDD is 0V, but 0-ohm
resistorjust in case that's wrong.
Connected to INT2, which features a countdown
timer only. Chosen because it's the only interrupt
that can create a wide pulse, e.g. up to 218.75ms
wide, long enough for FPGA to init and stay
alive.

All GPIOs are 3.3Vlevels.
I2C & LED is on U-domain.
VSYS_T provided for LED
backlight power

Top-side FPC (pack + speaker + backlight + GPIO)

Reference analog inputs to global
ground to help cancelglobal
ground noise.

GND 4

U<->S domain RAM CE isolation

Reset monitor Anti-glitch

Constraints:
Sets the standby clockfrequency ofthe
FPGA in low power modes (MMCM
turned off)

MMCM min frequency is 10MHz
PLL min frequency is 19MHz

12 MHz is the lowest frequency that meets
MMCM spec in the SiT8021 series

Power note: idle TMS
at '1', TCK at '0'.

AB-RTCMC-32.768KHZ-B5ZE-S3-T
RTC alarmfields abused to store "power-down clean" bit

https://github.com/betrusted-io
License: CERN-OHL-L
https://www.ohwr.org/project/cernohl/wikis/home

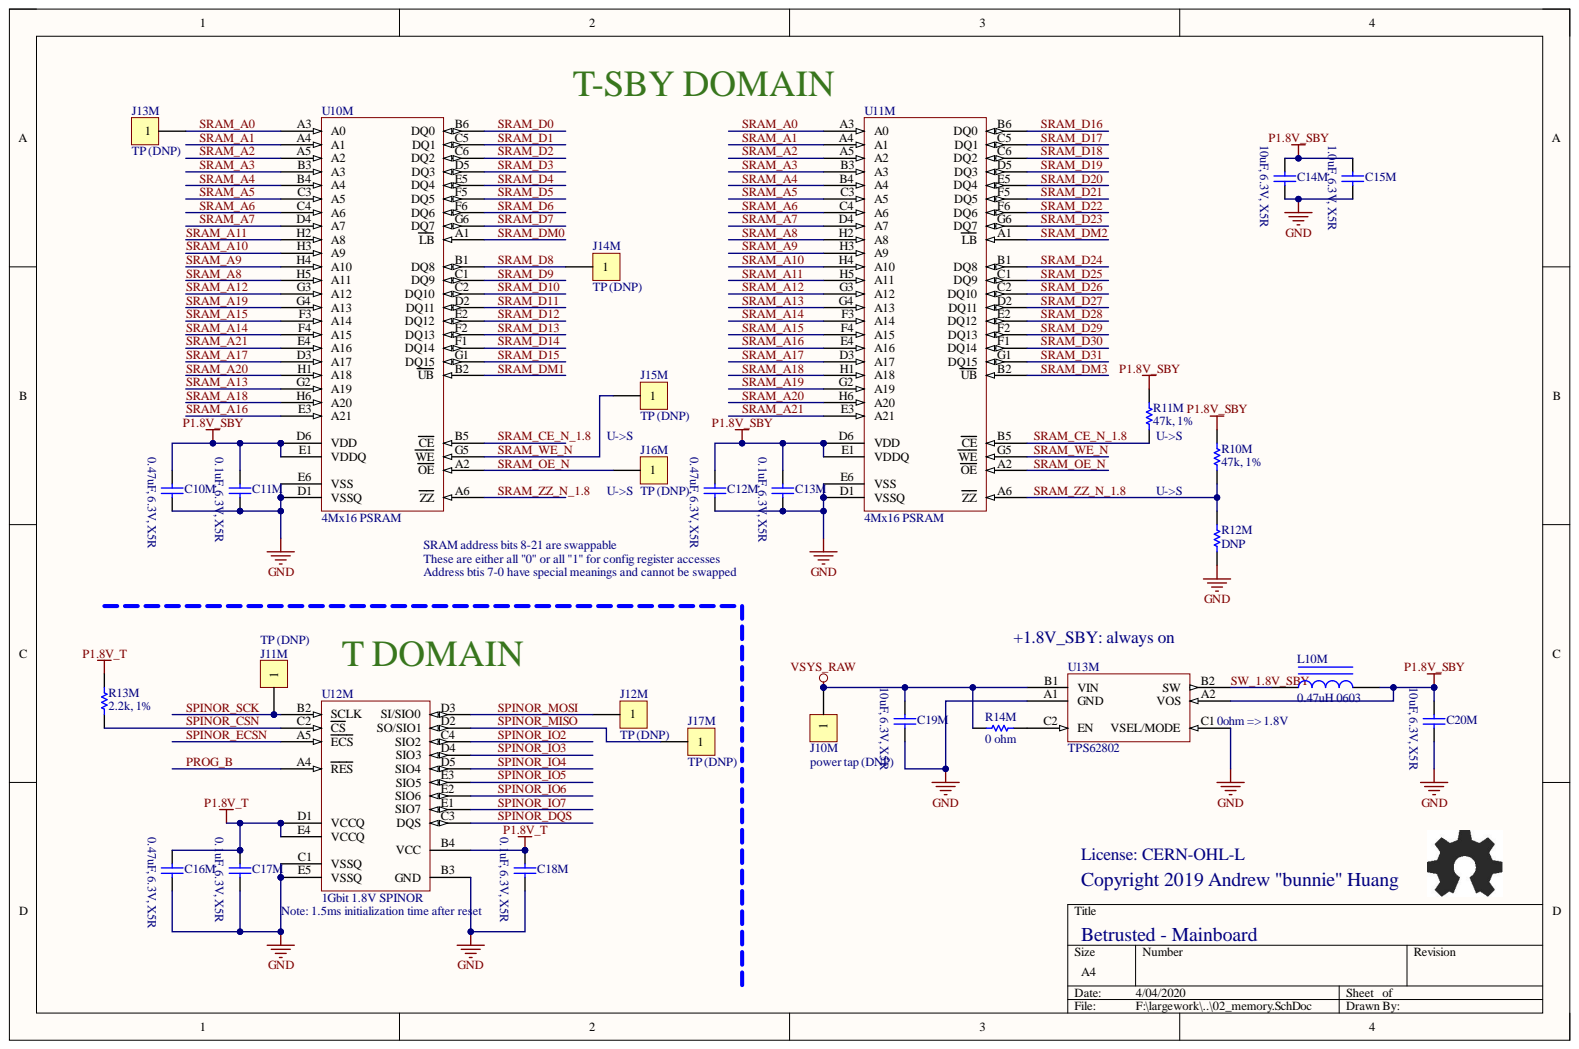
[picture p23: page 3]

SRAM address bits 8-21 are swappable
These are either all "0" or all "1" for config register accesses
Address btis 7-0 have special meanings and cannot be swapped

VCCQ E4

License: CERN-OHL-L
Copyright 2019 Andrew "bunnie" Huang

C17M | VSSQ E5

Note: 1.5ms initialization time after reset

Size A4 | Number | Revision

Date: 4/04/2020 | Sheet of
File: F:\largework\..\02_memory.SchDoc | Drawn By:

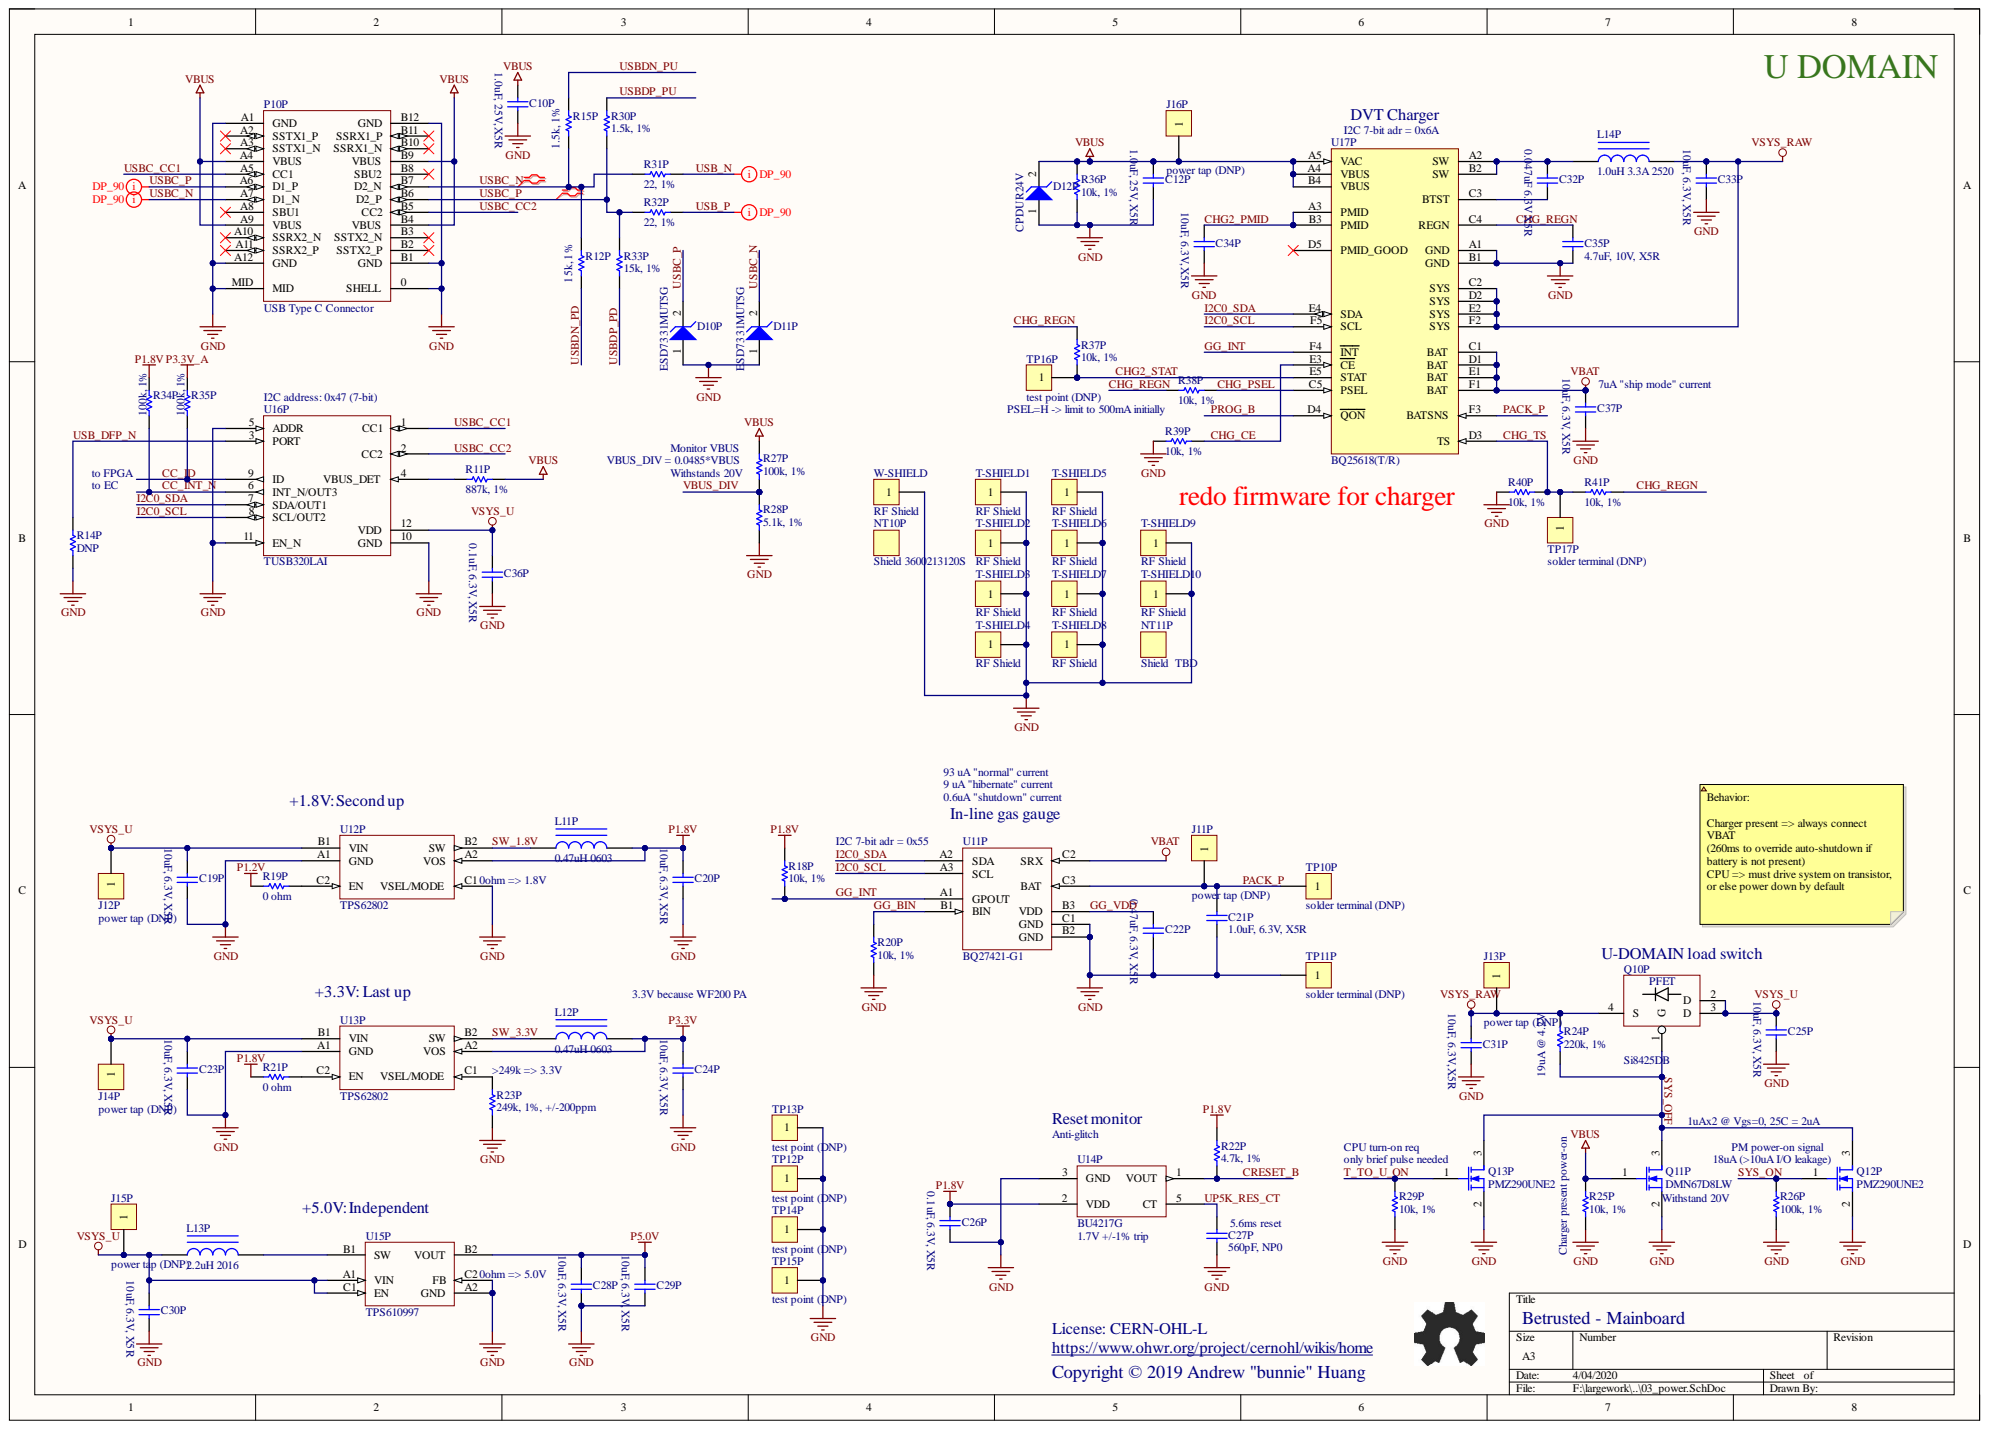
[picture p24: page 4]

DVT Charger I2C 7-bit adr = 0x6A

test point (DNP)
PSEL=H -> limit to 500mA initially

93 uA "normal" current
9 uA "hibernate" current
0.6uA "shutdown" current
In-line gas gauge

Charger present => always connect
VBAT
(260ms to override auto-shutdown if
battery is not present)
CPU => must drive system on transistor,
or else power down by default

PFET

power tap (DNP)

Reset monitor Anti-glitch

CPU turn-on req
only brief pulse needed

Charger present power-on

License: CERN-OHL-L
https://www.ohwr.org/project/cernohl/wikis/home

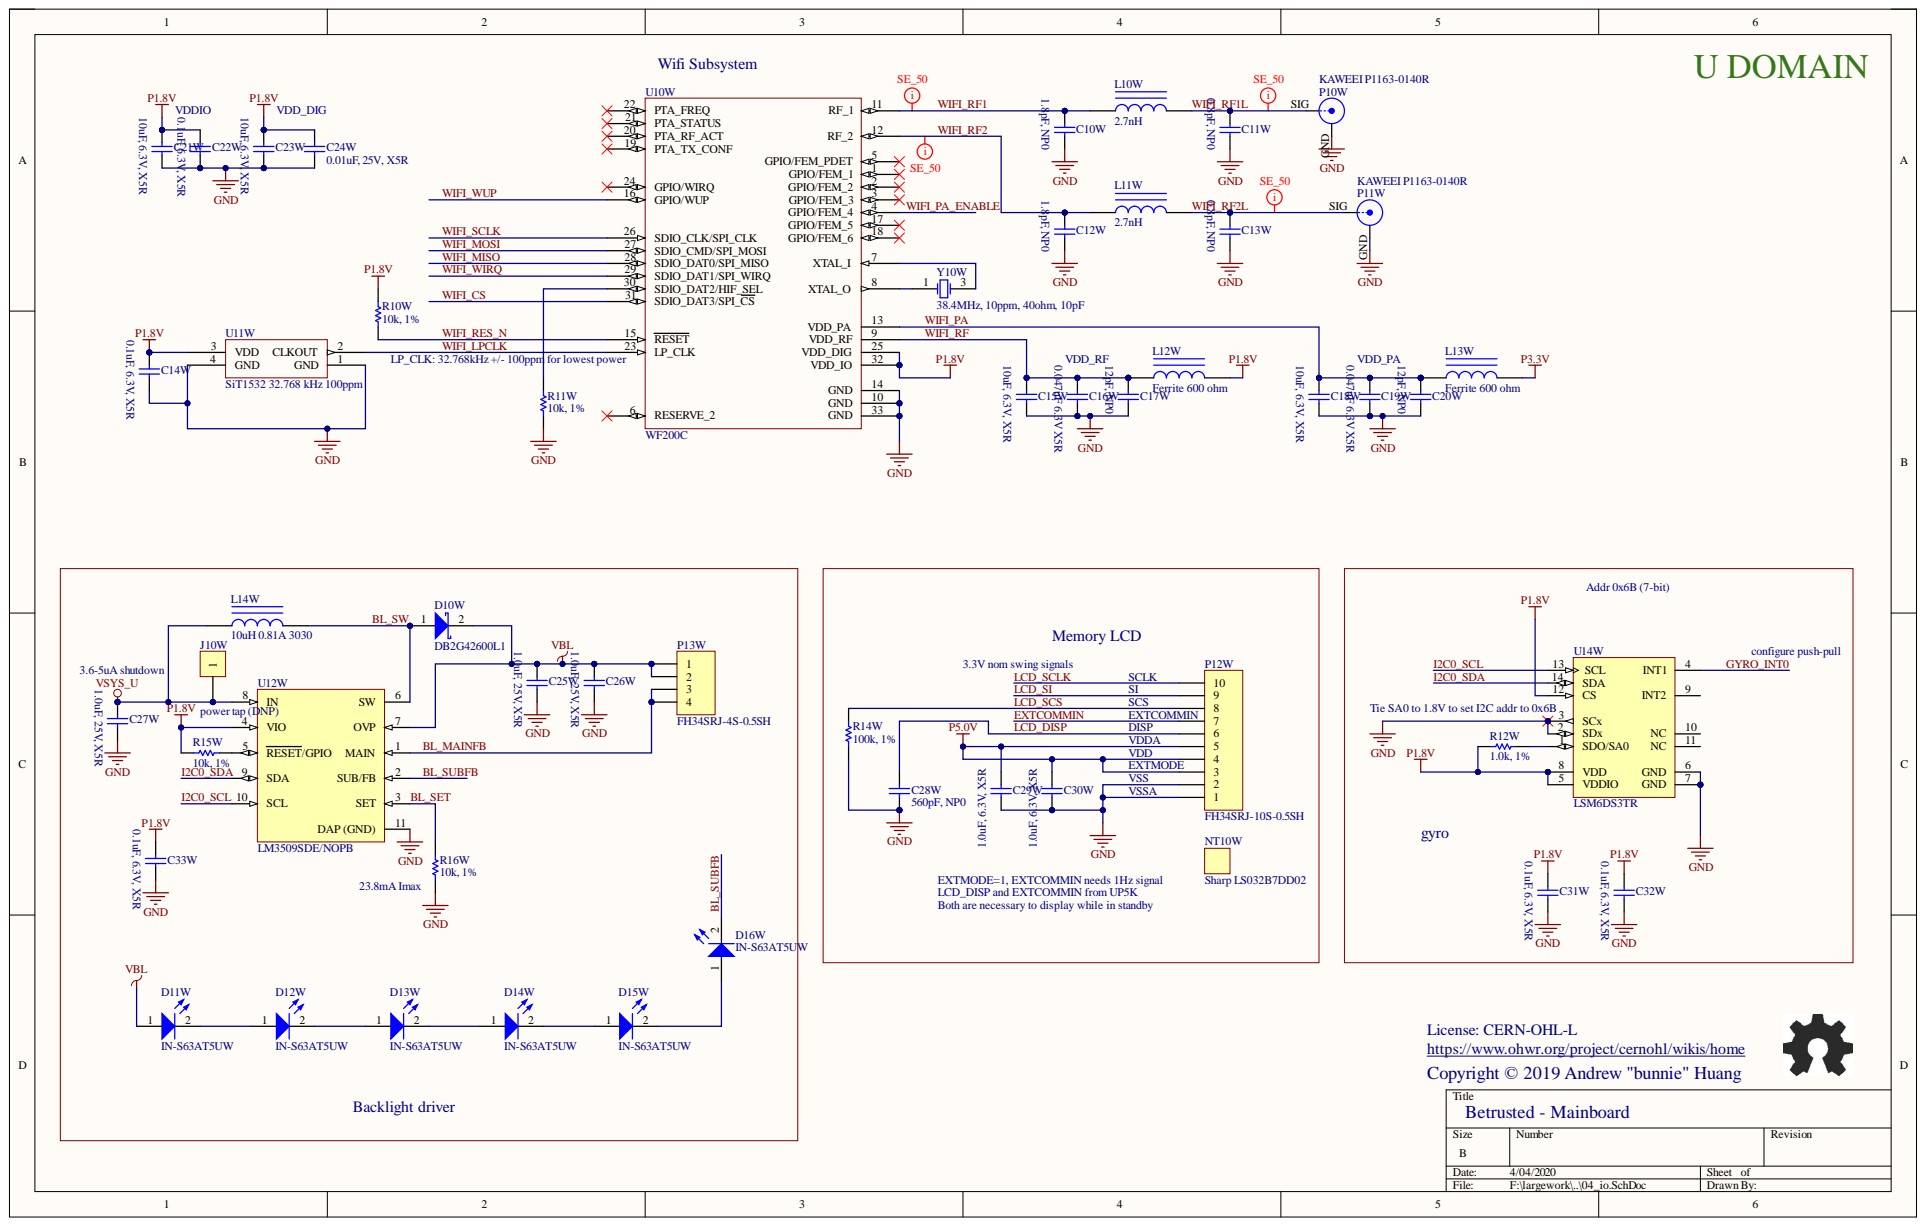
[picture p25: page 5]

RESET 15

GND 4 | | RESERVE_2 6 | P1.8V

Tie SA0 to 1.8V to set I2C addr to 0x6B

VDD
EXTMODE
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

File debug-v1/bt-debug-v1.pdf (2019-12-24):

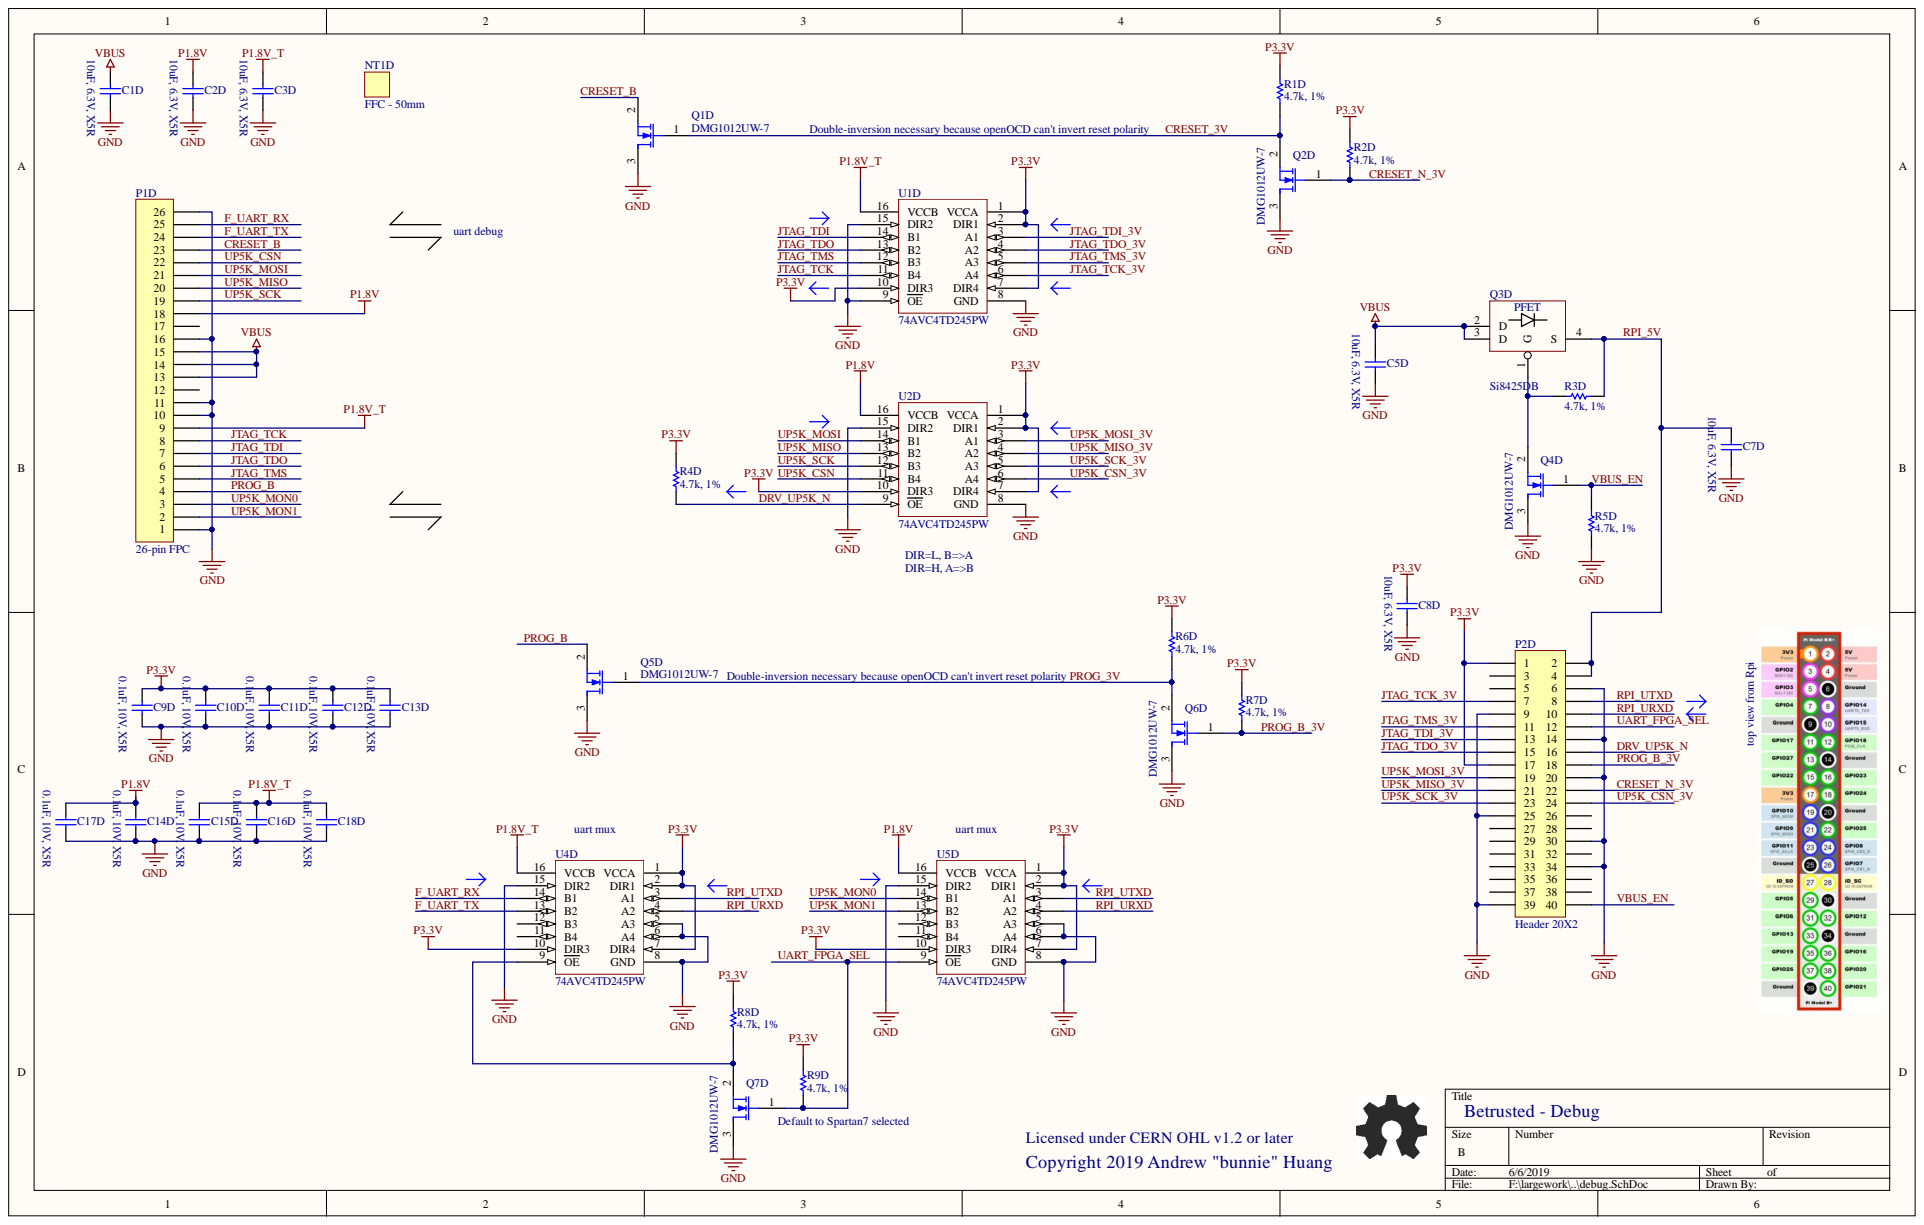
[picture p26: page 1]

Double-inversion necessary because openOCD can't invert reset polarity

top view from Rp

Licensed under CERN OHL v1.2 or later
Copyright 2019 Andrew "bunnie" Huang

Size B | Number | Revision

Date: 6/6/2019 | Sheet of
File: F:\largework\..\debug.SchDoc | Drawn By:

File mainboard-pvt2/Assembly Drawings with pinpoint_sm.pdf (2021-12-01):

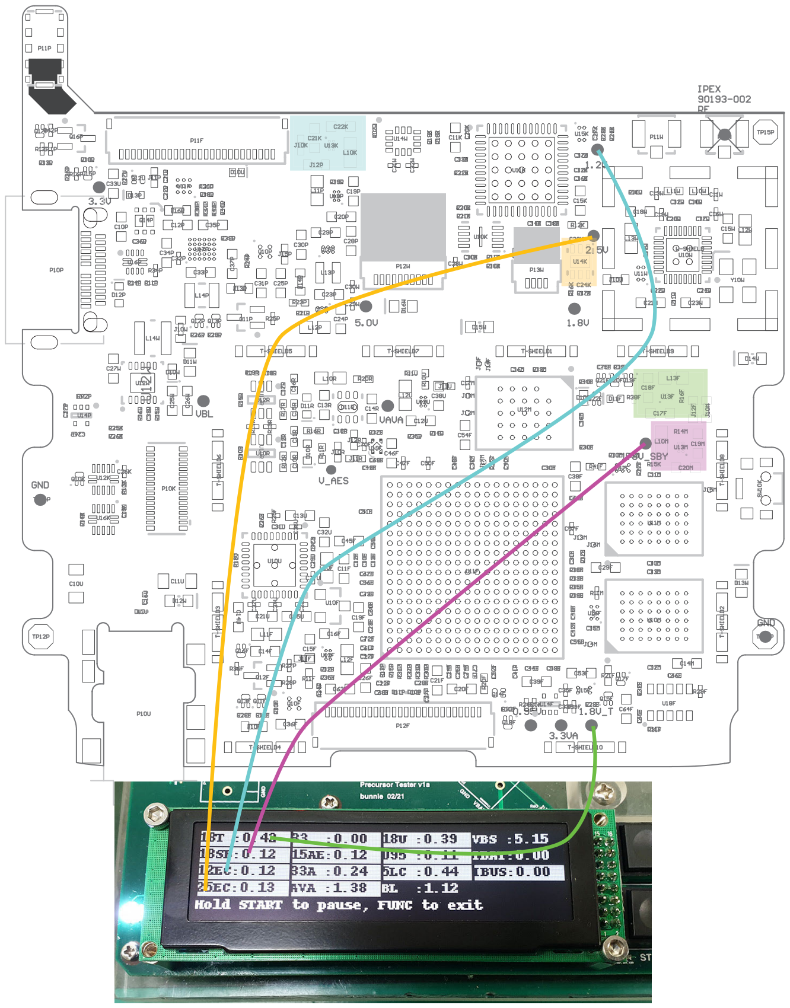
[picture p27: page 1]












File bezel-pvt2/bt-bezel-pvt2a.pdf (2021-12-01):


https://home.sandiego.edu/~ekim/e194rfs01/jwmatcher/matcher2.ht


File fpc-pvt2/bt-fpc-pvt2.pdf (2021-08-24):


Betrusted - FPC License: CERN-OHL-L

.org/project/cernohl/wikis/home (https://www.ohwr.org/project/cernohl/wikis/home)

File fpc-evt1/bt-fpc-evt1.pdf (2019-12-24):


R1 | 5 | | 1 M AIN F B

Betrusted - FPC License: CERN-OHL-L

.org/project/cernohl/wikis/home (https://www.ohwr.org/project/cernohl/wikis/home)


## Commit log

2019-12-24 initial commit of EVT hardware files
    [00_map.SchDoc, 01_fpga.SchDoc, 02_memory.SchDoc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]
2020-07-13 v3 keyboard design files: PCB, layouts, and overlay spec
    [Mirrorkeycap.sldprt, betrusted-kbd-v3.PrjPcb, bt-kbd-v3a.PcbDoc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]
2020-07-13 DVT version case files
    [CUI_DEVICES_SJ-3542AS-SMT-TR-67.SLDPRT, CUI_DEVICES_SJ-3542AS-SMT-TR-67.step, CUI_DEVICES_SJ-43615TS-SMT-TR.SLDPRT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]
2020-07-13 bezel design files for DVT1 rev
    [bt-bezel-dvt2-R.PcbDoc, bt-bezel-dvt2.PrjPcb, connectors.SchDoc]
2020-08-17 add DVT1 release design files
    please note this is still not production ready, do not use
    for production. This stage of design still has a couple of
    bugs that have been identified and will be fixed in PVT release.
    [00_map.SchDoc, 01_fpga.SchDoc, 02_memory.SchDoc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]
2020-11-24 fix missing embedded images, issue #2
    [00_map.SchDoc]
2021-08-24 add PVT2 files for the mainboard
    [00_map.SchDoc, 01_fpga.SchDoc, 02_memory.SchDoc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]
2021-08-24 add MP bezel files
    [bt-bezel-pvt1.PrjPcb, bt-bezel-pvt2a_final_mp.PcbDoc, connectors.SchDoc]
2021-08-24 forgot a schematic
2021-08-24 update keyboard files
    [bt-kbd-v3b.PcbDoc, kbd.SchDoc]
2021-08-24 and rpi debug HAT files
    [breakout.SchDoc, debug.SchDoc, rpi-hat-v3.PrjPcb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]
2021-08-24 add FPC designs
    [bt-fpc-pvt2.PrjPcb, bt-fpc-pvt2b.PcbDoc, bt-fpc-pvt2b.step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]
2021-08-31 add v4 (supply chain shortage adjustments) version of rpi hat
    [breakout.SchDoc, debug.SchDoc, rpi-hat-v4.PrjPcb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]
2021-09-03 update case design files
2021-11-29 add testjig files
    [interfaces.SchDoc, testcore.SchDoc, testjig-v1.PrjPcb]
2022-02-10 add a diagram explaining the parts of the PCB
2022-02-10 add a raw photo of the circuit board with no annotations
2022-03-17 add scissor switch version of braille keyboard
    [betrusted-kbd-braille4.PrjPcb, bt-bezel-braille4-kailh.PcbDoc, kbd.SchDoc]
2022-03-17 add interposer docs
    [betrusted-kbd-interposer.PrjPcb, bt-kbd-interposer.PcbDoc, interposer.SchDoc]
